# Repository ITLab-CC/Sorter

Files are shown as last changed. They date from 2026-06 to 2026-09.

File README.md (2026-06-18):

# AI-Sorter

An AI-powered marble sorting machine. A camera detects falling marbles, a neural network classifies them by color, and a solenoid actuator sorts them into the correct bin — all in real time on a Raspberry Pi with a Coral Edge TPU.

## What You Need

This project requires **two machines**:

### Raspberry Pi (runs the sorter)

| Component | Description |
|---|---|
| **Raspberry Pi** | Runs the sorting software (tested on Pi 4/5, Ubuntu 22.04 ARM64) |
| **FLIR Machine Vision Camera** | Captures images of marbles (uses the Spinnaker SDK) |
| **Coral USB Accelerator** | Runs the trained model for real-time inference (~6 ms/frame) |
| **Elevator motor** | Feeds marbles into the sorting area |
| **Solenoid actuator** | Diverts marbles into the correct bin |
| **NeoPixel LED strip** | Illuminates the sorting area for consistent images |
| **Light-beam sensor** | Detects when a marble passes through |

### Training PC (trains the AI model)

| Component | Description |
|---|---|
| **PC with NVIDIA GPU** | Trains the SSD MobileNet V2 model (fine-tuning ~50 000 steps) |
| **Docker + NVIDIA Container Toolkit** | The training pipeline runs inside a Docker container with GPU access |

> The training PC can be a local desktop, a cloud VM (AWS EC2, Google Cloud, etc.), or Google Colab. **Do not attempt training on the Raspberry Pi.**

## Step-by-Step Guide

Follow the guides below in order:

| Step | Guide | Machine |
|---|---|---|
| 0 | [Build the Sorter](docs/00-build-the-sorter.md) | Workbench |
| 1 | [Raspberry Pi Setup](docs/01-raspberry-pi-setup.md) | Raspberry Pi |
| 2 | [Training PC Setup](docs/02-training-pc-setup.md) | Training PC |
| 3 | [Create a Dataset](docs/03-create-dataset.md) | Raspberry Pi |
| 4 | [Train the Model](docs/04-train-model.md) | Training PC |
| 5 | [Run the Sorter](docs/05-run-sorter.md) | Raspberry Pi |

> **Don't want to train your own model?** A **pretrained, ready-to-use** model
> is included in [`my-models-example/`](my-models-example/README.md). Just copy
> that folder's contents into `my-models/` and skip straight to
> [Step 5 — Run the Sorter](docs/05-run-sorter.md) (you can ignore Steps 2–4).
> See [Step 5](docs/05-run-sorter.md) for the exact copy command.

## Project Structure

```
.
├── actuator/          # Motor, solenoid and LED control
├── sensor/            # Camera and light-beam sensor
├── dataset/           # Training images (created in step 3)
├── my-models/         # Trained models (created in step 4, git-ignored)
├── my-models-example/ # Pretrained ready-to-use model (copy into my-models/)
├── docs/              # Step-by-step setup guides
├── create_unlabeled_dataset.py
├── label_dataset.py
├── label_map.pbtxt    # Single source of truth for class labels
├── main.py            # Entry point for the sorter
├── Dockerfile.train   # Docker image for training
└── pipeline.config    # SSD MobileNet V2 training config
```

## Label Map (`label_map.pbtxt`)

`label_map.pbtxt` is the **single source of truth** for all class labels used throughout the project. Every script — labeling, TFRecord generation, training, and inference — reads its labels from this file. Never hardcode label names or IDs elsewhere.

The file uses the [TensorFlow Object Detection API label map format](https://github.com/tensorflow/models/blob/master/research/object_detection/data/kitti_label_map.pbtxt). Each class gets an `item` block with a unique `id` (starting at 1) and a `name`:

```protobuf
item {
  id: 1
  name: 'black'
}

item {
  id: 2
  name: 'green'
}

item {
  id: 3
  name: 'orange'
}

item {
  id: 4
  name: 'red'
}

```

To add or change marble colors:

1. Edit `label_map.pbtxt` — add, remove, or rename entries.
2. Make sure a matching `dataset/<name>/` folder with images exists for each label (see [Step 3](docs/03-create-dataset.md)).
3. Update `num_classes` in `pipeline.config` to match the number of items in `label_map.pbtxt`.
4. Re-run the labeling and training pipeline as usual — all scripts pick up the changes automatically.

## Sources

- **Model:** [SSD MobileNet V2 320x320 (COCO17 TPU-8)](http://download.tensorflow.org/models/object_detection/tf2/20200711/ssd_mobilenet_v2_320x320_coco17_tpu-8.tar.gz)
- **Framework:** [TensorFlow Object Detection API](https://github.com/tensorflow/models/tree/master/research/object_detection)
- **Edge TPU compiler:** [coral.ai/docs/edgetpu/compiler](https://coral.ai/docs/edgetpu/compiler/)

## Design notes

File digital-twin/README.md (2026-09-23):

# KI-Sorter · Digitaler Zwilling

Interaktives 3D-Modell des Murmelsortierers als Next.js-Web-App. Die App lädt
die **originalen 3MF-Dateien** aus [`../3d-files/3mf`](../3d-files/3mf), setzt sie
wie im echten Aufbau zusammen und zeigt den Ablauf:

```
Vorratskasten → Archimedes-Schnecke → Steigrohr → Trichter → Kamerakammer (LED + FLIR)
             → Erkennung → Hubmagnet kippt die Rinne → Auslauf links / rechts → Becher
```

Es gibt keine KI und keine Physik-Simulation: Die Murmeln folgen fest definierten
Wegpunkten. Das Modell zeigt, wie die Maschine funktioniert, und lässt sich später
über einen WebSocket mit dem echten Sorter verbinden.

## Starten

```bash
cd digital-twin
npm install
npm run dev          # http://localhost:3000
```

`npm run dev` / `npm run build` kopieren vorher automatisch alle `.3mf` aus
`../3d-files/3mf` nach `public/models` (`scripts/sync-models.mjs`). Wer ein Teil in
Fusion neu exportiert, sieht es also direkt in der Web-App.

Deep-Links für Präsentationen: `/?view=chamber`, `/?view=gate&xray=1`
(`overview`, `chamber`, `gate`, `transporter`).

## Bedienung

- **Simulation**: START/STOP wie am Touchscreen, Murmeln einer Farbe gezielt einwerfen,
  Zähler zurücksetzen.
- **Echter Sorter**: WebSocket-Adresse eintragen und verbinden, dann zeigt das Modell
  den Live-Zustand des Raspberry Pi.
- Maus über ein Bauteil zeigt Name, Funktion und Quelldatei. Klick hält die Auswahl fest.
- **Röntgenblick** macht die Gehäuse durchsichtig, so sieht man die Murmel in Kammer,
  Weiche und Steigrohr.
- Baugruppen lassen sich einzeln ausblenden.

Sortierregel wie in `main.py`: Grün/Orange → Magnet AN → **links**,
Rot/Schwarz → Magnet AUS → **rechts**.

## Anbindung an den echten Sorter

Die App ist so gebaut, dass nur die Datenquelle wechselt, die Szene bleibt gleich:

| Datei | Aufgabe |
|---|---|
| `lib/twin/types.ts` | Datenmodell (`TwinState`) und Nachrichtenformat (`LiveMessage`) |
| `lib/twin/store.ts` | Zustand + Ereignisse (`release`, `detection`) |
| `lib/twin/sources.ts` | `SimulationSource` (Demo) und `LiveSource` (WebSocket) |
| `bridge/twin_bridge.py` | WebSocket-Server für den Raspberry Pi |

Nachrichten (JSON, eine pro WebSocket-Frame; alle `state`-Felder optional):

```json
{"type": "state", "running": true, "motor": true, "solenoid": false,
 "led": {"rgb": [255, 255, 255], "brightness": 0.5}}
{"type": "detection", "label": "green", "confidence": 0.93, "side": "left"}
{"type": "release", "label": "red"}
{"type": "reset"}
```

Ohne Hardware testen:

```bash
pip install websockets
python bridge/twin_bridge.py --demo
# Web-App → „Echter Sorter“ → ws://localhost:8765 → Verbinden
```

Später in `main.py` einbinden (nicht blockierend, eigener Thread):

```python
from twin_bridge import TwinBridge          # Datei auf den Pi kopieren
twin = TwinBridge(port=8765); twin.start()

# bei START / STOP
twin.state(running=True, motor=True, led=((255, 255, 255), 0.5))
twin.state(running=False, motor=False, solenoid=False, led=((0, 255, 0), 0.05))

# nach jeder Klassifizierung
twin.detection(label, confidence / 100, "left" if label in ("green", "orange") else "right")
twin.state(solenoid=label in ("green", "orange"))
```

## Aufbau des 3D-Modells

- Alle Teile werden in einem gemeinsamen Koordinatensystem platziert:
  Z oben, Millimeter, Tischplatte bei z = 0 (`lib/layout.ts`).
- Jedes Teil hat `basis` (Ausrichtung), `pivot` (Bezugspunkt im Teil) und `at`
  (Position in der Welt). Die Maße stammen direkt aus den Meshes.
- Zukaufteile ohne 3MF-Datei (NEMA-17, FLIR-Kamera mit Objektiv, 7"-Display,
  NeoPixel-Ring, Platinen, Laborstativ) sind einfache Grundkörper
  (`components/scene/Hardware.tsx`).
- `/debug?part=Kamera/main_chamber,Kamera/Deckel` zeigt Teile in ihrem eigenen
  Koordinatensystem aus vier Richtungen. Das hilft beim Ausrichten neuer Teile.

Bewusst weggelassen: `Case.3mf` (auf den Fotos nicht verbaut),
`Kurbelschleifen_Funktionstester.3mf` (Testvorrichtung), `Kurbelschleife.3mf`
(sitzt verdeckt im Magnetgehäuse der Weiche). Die Anordnung ist nach den
Aufbaufotos rekonstruiert. Hilfsstützen aus der Bauphase fehlen.

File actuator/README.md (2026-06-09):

# Information about the Actuator module.
This folder contains the code for the Actuator module, which is responsible for controlling the physical components of the system. It includes code for:
- Motor elevator for marbles
- Solenoid motor for a marble switch to change the path of the marbles
- LED neopixel ring to make a picture of the marbles falling down

# Installation

```bash
python3 -m venv .venv-3.10
source .venv-3.10/bin/activate
pip install -r requirements-3.10.txt
```

# Usage

```bash
sudo .venv-3.10/bin/python [script].py
```

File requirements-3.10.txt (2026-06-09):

numpy<2
Pillow
opencv-python
# Wheels from https://github.com/cappittall/pycoral_whl_4_python3.10/tree/main/tools
# Install manually:
#   pip install ./tflite_runtime-2.5.0.post1-cp310-cp310-linux_x86_64.whl
#   pip install ./pycoral-2.0.0-cp310-cp310-linux_x86_64.whl

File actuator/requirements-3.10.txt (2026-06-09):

mypy
RPi.GPIO
Adafruit-Blinka
adafruit-circuitpython-neopixel
gpiozero

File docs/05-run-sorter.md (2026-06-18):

# Step 5 — Run the Sorter

You now have a trained Edge TPU model. Time to sort some marbles.

> **Machine:** Raspberry Pi

## 5.1 Get a model into `my-models/`

The sorter loads its model from the `my-models/` folder (which is git-ignored). You have two options:

### Option A — Use the included pretrained model (no training required)

If you don't want to train your own model, a **pretrained, ready-to-use** model ships with the project in `my-models-example/`. Just copy its contents into `my-models/`:

```bash
# From the project root, on the Raspberry Pi
mkdir -p my-models
cp my-models-example/marbel_coral.tflite my-models-example/labels.txt my-models/
```

That's it — you can skip Steps 2–4 entirely. See [`my-models-example/README.md`](../my-models-example/README.md) for details about the model.

### Option B — Use your own trained model

If you completed [Step 4 — Train the Model](04-train-model.md), transfer `my-models/marbel_coral.tflite` and `my-models/labels.txt` from the training PC to the Raspberry Pi project directory (inside `my-models/`).

## 5.2 Start the sorter

Make sure the camera, Coral USB Accelerator, motors, and sensors are all connected, then run:

```bash
sudo .venv-3.10/bin/python main.py
```

Enjoy your sorted marbles!

## 5.3 Run automatically on boot (autostart)

To make the sorter start by itself once the desktop appears, use the **labwc** autostart script (Raspberry Pi OS Bookworm/trixie use the labwc Wayland compositor).

We run the app inside a detached [`screen`](https://www.gnu.org/software/screen/) session named `sorter`, so you can attach later to see its console output.

1. Make sure `screen` is installed:

   ```bash
   sudo apt install screen
   ```

2. Create the file `~/.config/labwc/autostart` with the following contents (adjust the paths if your project lives elsewhere):

   ```sh
   #!/bin/sh
   # Start the marble sorter app in a detached screen session after the desktop comes up
   cd /home/sorter/Documents/Sorter
   screen -dmS sorter sudo --preserve-env=WAYLAND_DISPLAY,XDG_RUNTIME_DIR .venv-3.10/bin/python main.py
   ```

   - `screen -dmS sorter` starts a **d**etached, na**m**ed (`sorter`) session in the background.
   - `sudo --preserve-env=WAYLAND_DISPLAY,XDG_RUNTIME_DIR` lets the root process reach the Wayland display (required because the app runs with `sudo` under Wayland). For this to work without a password prompt, passwordless `sudo` must be configured (it is by default on Raspberry Pi OS for the default user).

3. Make it executable:

   ```bash
   chmod +x ~/.config/labwc/autostart
   ```

4. Test it without rebooting, then reboot to confirm:

   ```bash
   ~/.config/labwc/autostart
   screen -ls          # should list the "sorter" session
   sudo reboot
   ```

### Managing the running session

| Action | Command |
| --- | --- |
| Attach to / view the app console | `screen -r sorter` |
| Detach again (leave it running) | press `Ctrl+a` then `d` |
| List sessions | `screen -ls` |
| Stop the sorter | `screen -XS sorter quit` |

---

**Previous:** [Step 4 — Train the Model](04-train-model.md)
**Back to:** [README](../README.md)

[**Home**](../README.md)

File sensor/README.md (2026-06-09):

# Information about the Actuator module.
This folder contains the code for the Sensors. The sensors are responsible for collecting data from the sorter. It includes code for:
- FLIR camera (500FPS)
- Light beam sensor

# Installation

## Docker
Downloade the python and the sdk version of the Spinnaker SDK from the following link: 

https://www.teledynevisionsolutions.com/support/support-center/software-firmware-downloads/iis/spinnaker-sdk-download/spinnaker-sdk--download-files/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

There should be two files:
- For x64 (PCs):
- - (Linux Ubuntu 22.04 -- 64-bit) 'spinnaker-4.3.0.189-Ubuntu22.04-amd64-pkg.tar.gz'
- - (Linux Ubuntu 22.04 -- 64-bit Python 3.10) 'spinnaker_python-4.3.0.189-cp310-cp310-linux_x86_64.tar.gz'

```bash
sudo docker build -t sorter-actuator .
sudo docker run -it --rm \
    --privileged \
    -v /dev/bus/usb:/dev/bus/usb \
    -v $(pwd)/out:/app/out \
    --shm-size=2g \
    sorter-actuator
```

## DEV
```bash
sudo apt update 
sudo apt install -y \
    udev \
    ethtool \
    libusb-1.0-0 \
    iproute2 \
    iputils-ping \
    net-tools \
    build-essential \
    libssl-dev \
    zlib1g-dev \
    libbz2-dev \
    libreadline-dev \
    libsqlite3-dev \
    curl \
    git \
    libncursesw5-dev \
    xz-utils \
    tk-dev \
    libxml2-dev \
    libxmlsec1-dev \
    libffi-dev \
    liblzma-dev \
    libgl1 \
    libglib2.0-0 \
    ffmpeg

curl https://pyenv.run | bash

echo 'export PYENV_ROOT="$HOME/.pyenv"' >> ~/.bashrc
echo 'command -v pyenv >/dev/null || export PATH="$PYENV_ROOT/bin:$PATH"' >> ~/.bashrc
echo 'eval "$(pyenv init -)"' >> ~/.bashrc
export PYENV_ROOT="$HOME/.pyenv"
command -v pyenv >/dev/null || export PATH="$PYENV_ROOT/bin:$PATH"
eval "$(pyenv init -)"

pyenv install 3.10.20

pyenv local 3.10.20
```

```bash
python3.10 -m venv .venv-3.10
source .venv-3.10/bin/activate
export SPINNAKER_GENTL64_CTI=/opt/spinnaker/lib/spinnaker-gentl/Spinnaker_GenTL.cti
pip install -r requirements-3.10.txt
```
---

Downloade the python and the sdk version of the Spinnaker SDK from the following link: 

https://www.teledynevisionsolutions.com/support/support-center/software-firmware-downloads/iis/spinnaker-sdk-download/spinnaker-sdk--download-files/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

There should be two files:
- For ARM (Raspberry PIs):
- - (Linux Ubuntu 22.04 --ARM64) 'spinnaker-4.3.0.189-Ubuntu22.04-arm64-pkg.tar.gz'
- - (Linux Ubuntu 22.04 -- ARM64 Python 3.10) 'spinnaker_python-4.3.0.189-cp310-cp310-linux_aarch64.tar.gz'

```bash
mkdir -p spinnaker_sdk spinnaker_python
tar -xzvf spinnaker-4.3.0.189-Ubuntu22.04-arm64-pkg.tar.gz -C spinnaker_sdk
tar -xzvf spinnaker_python-4.3.0.189-cp310-cp310-linux_aarch64.tar.gz -C spinnaker_python

cd spinnaker_sdk/spinnaker-4.3.0.189-arm64/
./install_spinnaker_arm.sh

cd ../../spinnaker_python
pip3 install spinnaker_python-4.3.0.189-cp310-cp310-linux_aarch64.whl

cd ..
rm -rf spinnaker_python spinnaker_sdk
```

---

- For x64 (PCs):
- - (Linux Ubuntu 22.04 -- 64-bit) 'spinnaker-4.3.0.189-Ubuntu22.04-amd64-pkg.tar.gz'
- - (Linux Ubuntu 22.04 -- 64-bit Python 3.10) 'spinnaker_python-4.3.0.189-cp310-cp310-linux_x86_64.tar.gz'

```bash
mkdir -p spinnaker_sdk spinnaker_python
tar -xzvf spinnaker-4.3.0.189-Ubuntu22.04-amd64-pkg.tar.gz -C spinnaker_sdk
tar -xzvf spinnaker_python-4.3.0.189-cp310-cp310-linux_x86_64.tar.gz -C spinnaker_python

cd spinnaker_sdk/spinnaker-4.3.0.189-amd64/
./install_spinnaker.sh

cd ../../spinnaker_python
pip3 install spinnaker_python-4.3.0.189-cp310-cp310-linux_x86_64.whl

cd ..
rm -rf spinnaker_python spinnaker_sdk
```

# Usage

```bash
sudo .venv-3.10/bin/python [script].py
```

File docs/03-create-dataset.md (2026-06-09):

# Step 3 — Create a Dataset

This guide walks you through capturing marble images and labeling them for training.

> **Machine:** Raspberry Pi

## 3.1 Capture images

Put only **one color** of marbles in the sorter at a time. Aim for at least **200 images per color**.

```bash
sudo .venv-3.10/bin/python create_unlabeled_dataset.py
```

The script will ask you for:
1. **Label name** — the marble color (e.g. `red`). The label is automatically added to `label_map.pbtxt` (skipped if it already exists) and the matching `dataset/<name>/` folder is created.
2. **Capture time** — how many seconds to run the camera.

To lift the elevator motor so you can swap marbles more easily:

```bash
sudo .venv-3.10/bin/python actuator/elevator_motor.py
```

Repeat for every color. You should end up with a folder structure like this:

```
dataset/
├── black/
│   ├── frame_0000.png
│   ├── frame_0001.png
│   └── ...
├── orange/
│   ├── frame_0000.png
│   └── ...
├── green/
│   └── ...
├── red/
│   └── ...
└── ...
```

## 3.2 Auto-label the images

This script uses OpenCV to detect marbles and generate bounding-box labels automatically. It reads the class names from `label_map.pbtxt` and processes only `dataset/` subfolders that match those names. The results are saved as `dataset-<color>.json` files inside the `dataset/` folder.

```bash
sudo .venv-3.10/bin/python label_dataset.py
```

Result should look like this:
```
dataset/
├── black
├── green
├── mixed-not-labeled
├── orange
├── red
├── white
├── dataset-black.json
├── dataset-green.json
├── dataset-orange.json
├── dataset-red.json
└── dataset-white.json
```

> The auto-labeler is not perfect — you **must** review and correct the labels in the next step.

## 3.3 Review labels with Label Studio

### Start Label Studio

```bash
curl -sSL https://get.docker.com | sudo sh
```

```bash
mkdir -p label-studio
sudo chown :0 label-studio
sudo docker run --network host \
  -v $(pwd)/label-studio:/label-studio/data \
  --name label-studio -d heartexlabs/label-studio:latest

echo "Label Studio is starting up. Please wait a moment (1min)..."
sleep 60
echo "Label Studio should now be running at http://localhost:8080 (oder über die IP-Adresse des Hosts)"
```

Open <http://localhost:8080> in your browser.

### Serve images locally

Label Studio needs HTTP access to the images. Start the included server on port 1000:

```bash
sudo python3 http-server.py
```

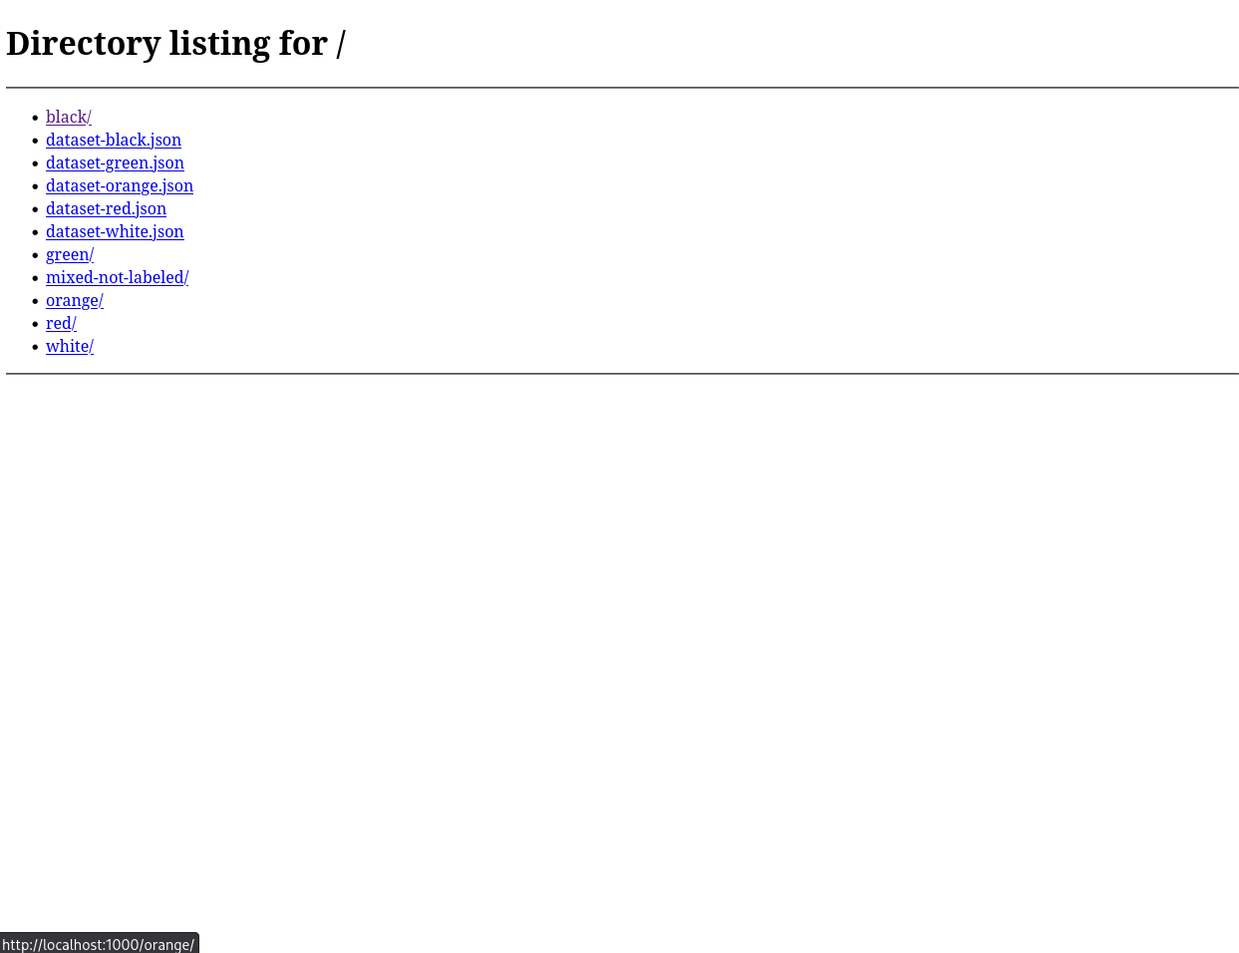
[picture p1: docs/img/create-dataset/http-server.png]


### Import and review

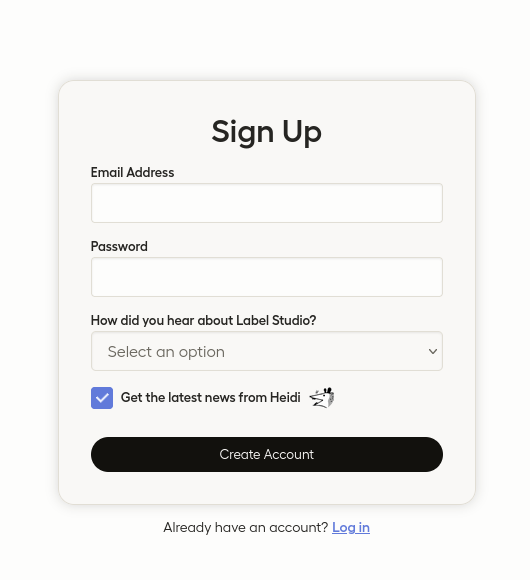
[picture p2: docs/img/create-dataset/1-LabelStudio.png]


1. Click **Import** in Label Studio.
2. Upload the `dataset-<color>.json` files from the `dataset/` folder.
3. Review each image and correct any wrong bounding boxes.

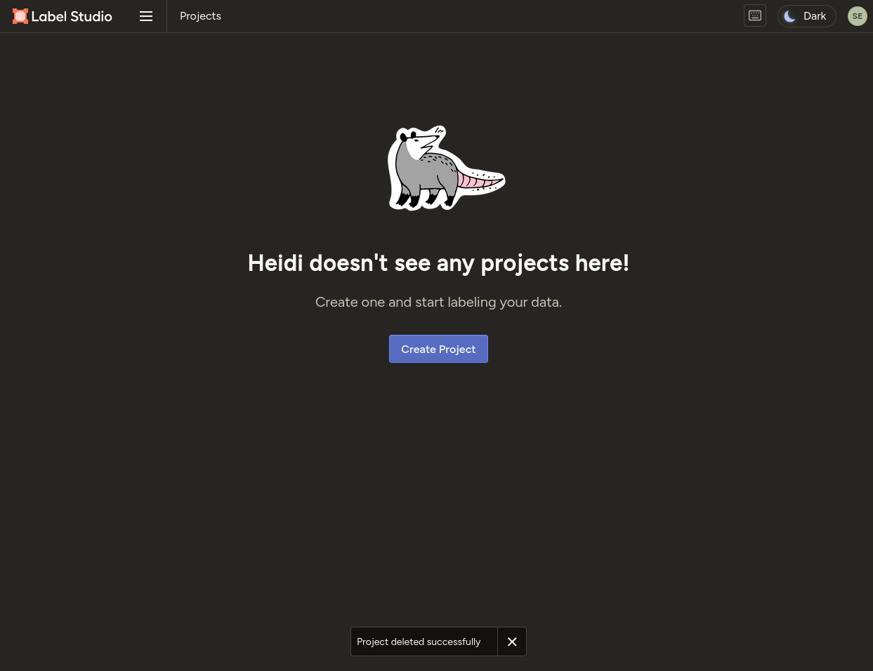
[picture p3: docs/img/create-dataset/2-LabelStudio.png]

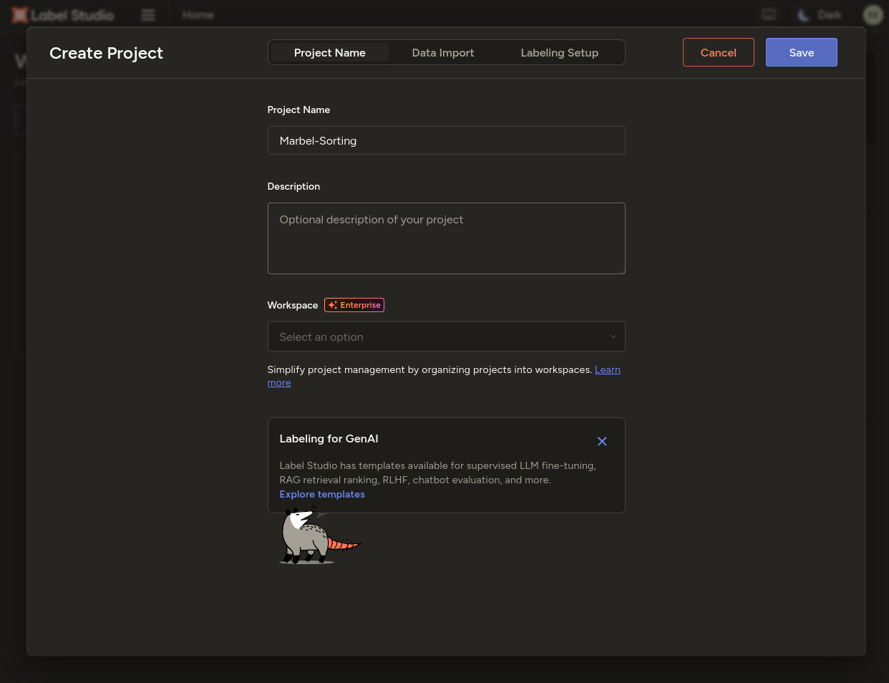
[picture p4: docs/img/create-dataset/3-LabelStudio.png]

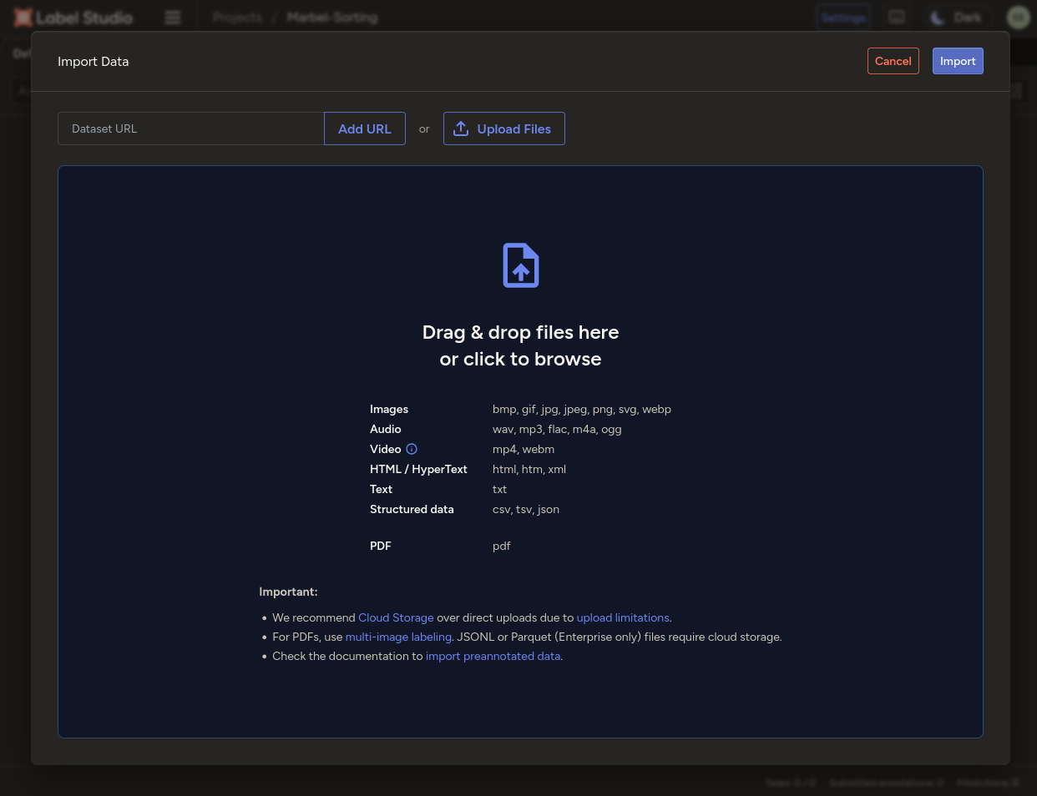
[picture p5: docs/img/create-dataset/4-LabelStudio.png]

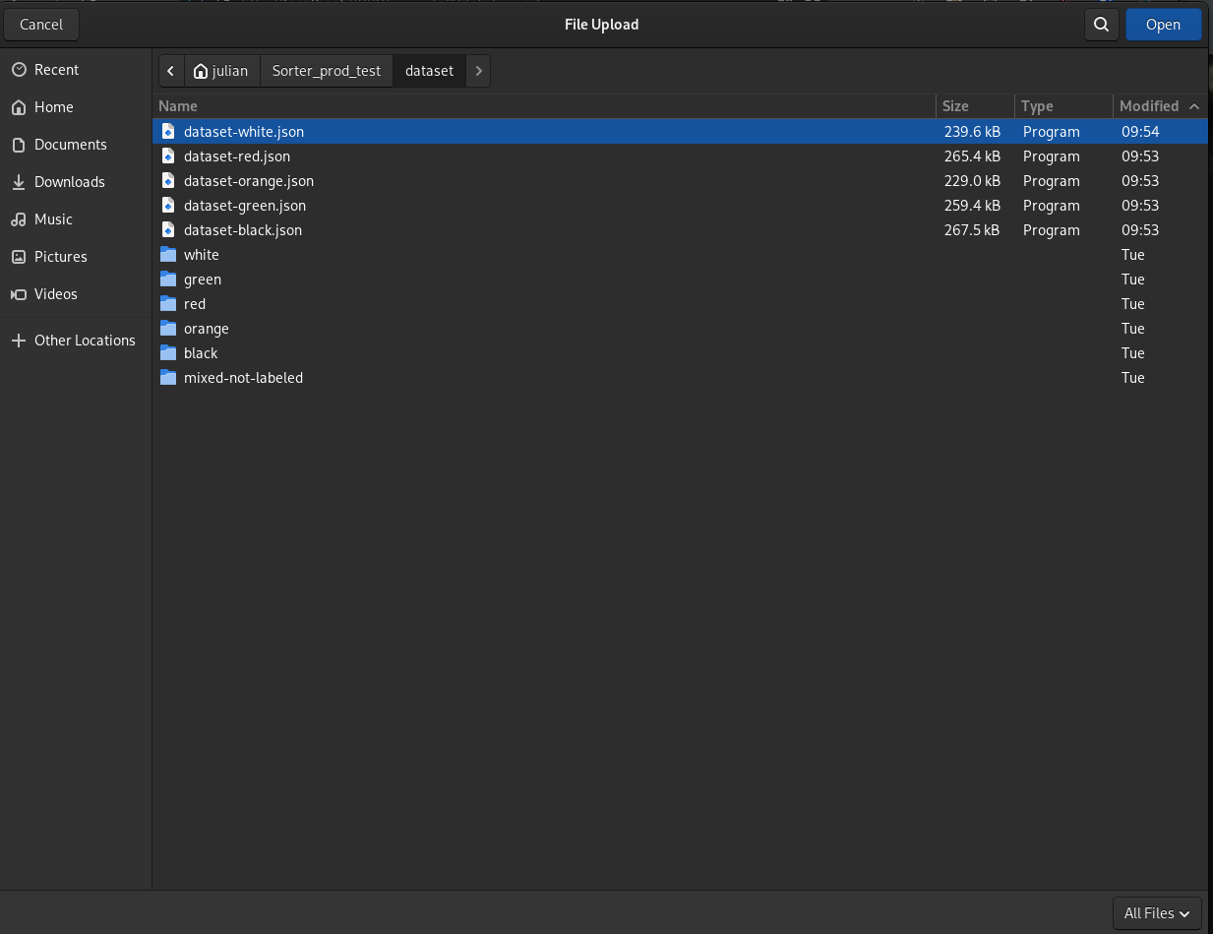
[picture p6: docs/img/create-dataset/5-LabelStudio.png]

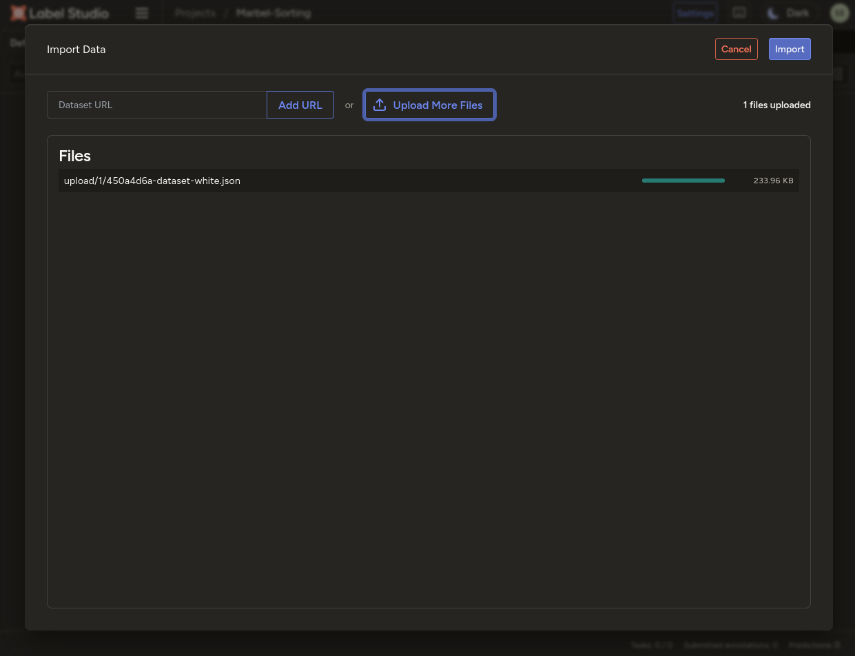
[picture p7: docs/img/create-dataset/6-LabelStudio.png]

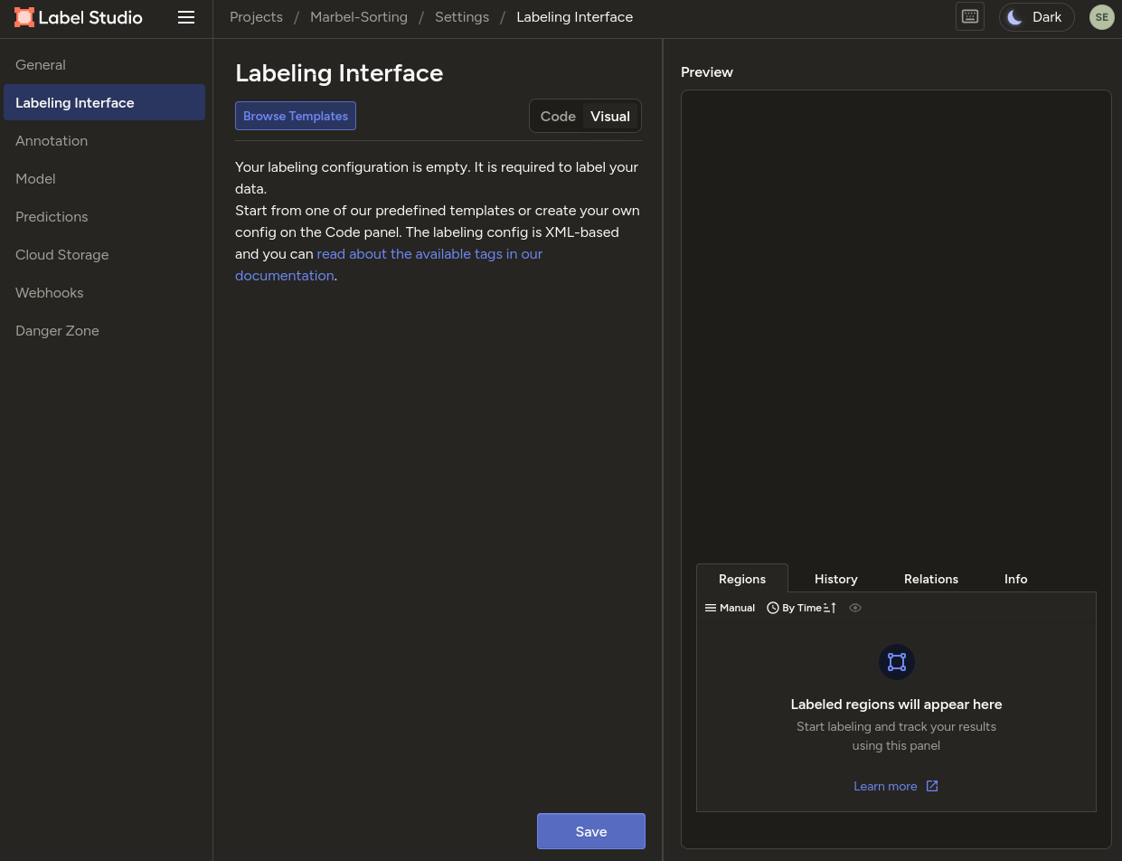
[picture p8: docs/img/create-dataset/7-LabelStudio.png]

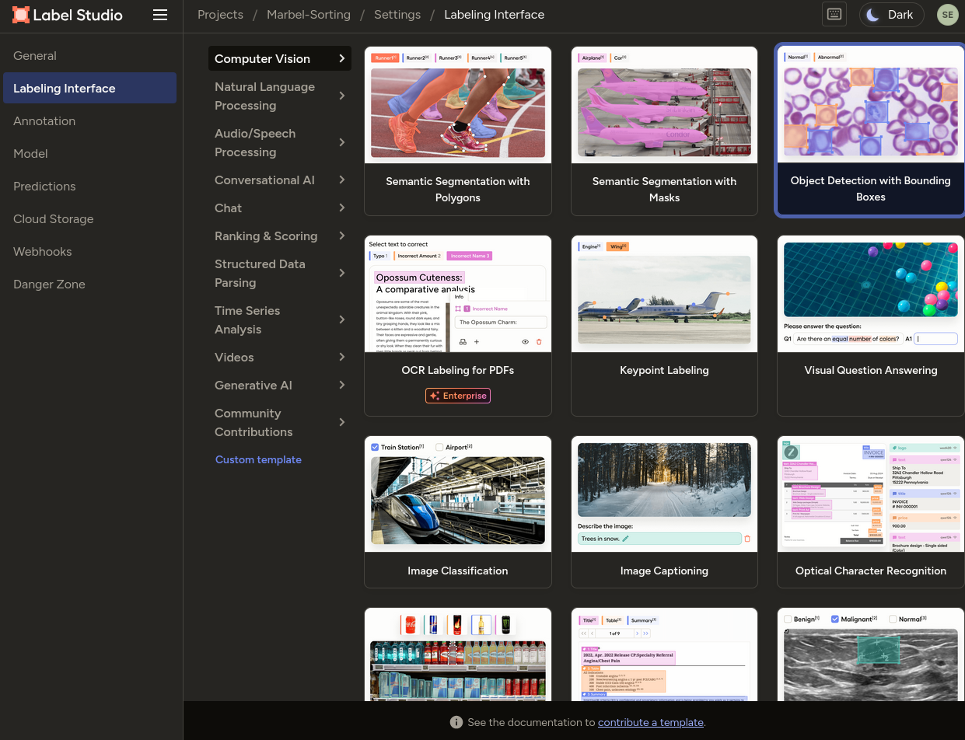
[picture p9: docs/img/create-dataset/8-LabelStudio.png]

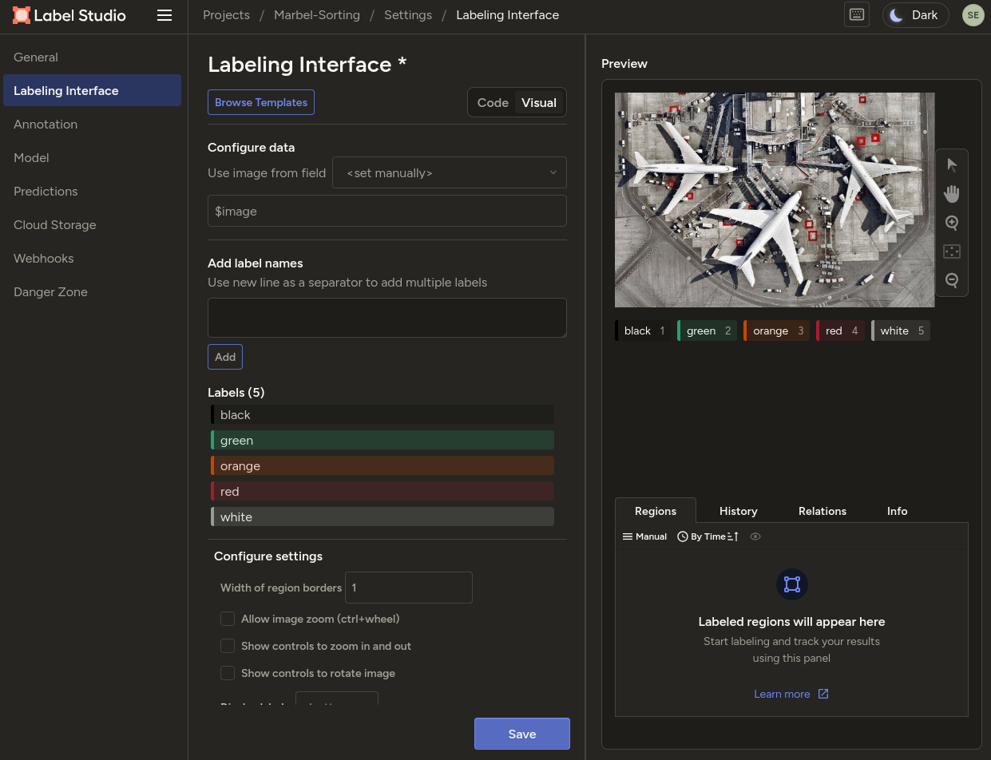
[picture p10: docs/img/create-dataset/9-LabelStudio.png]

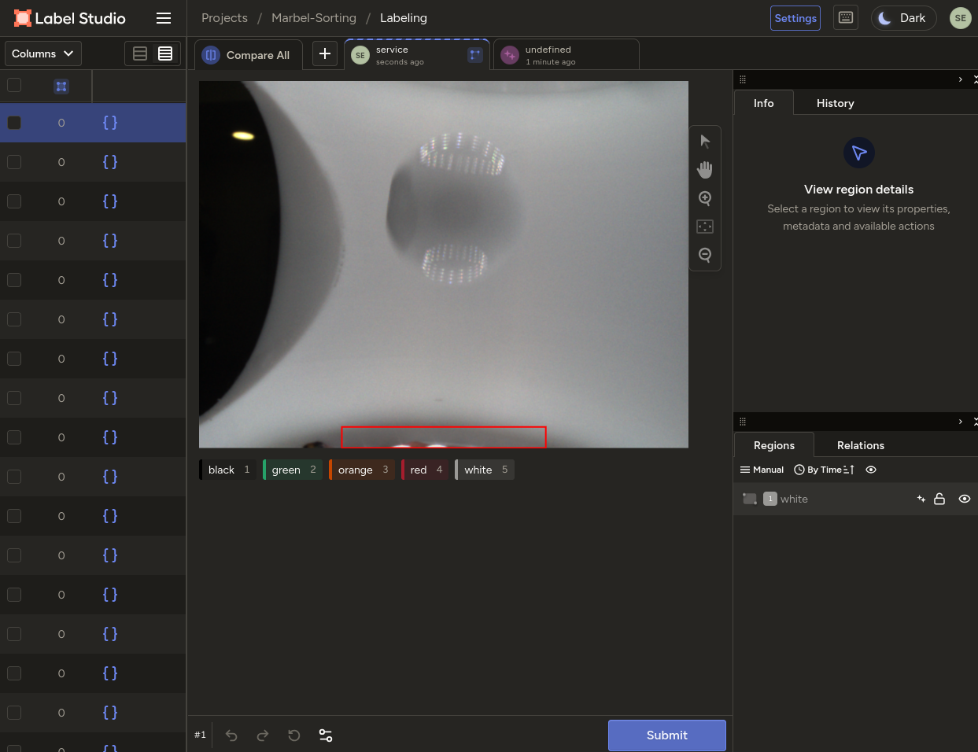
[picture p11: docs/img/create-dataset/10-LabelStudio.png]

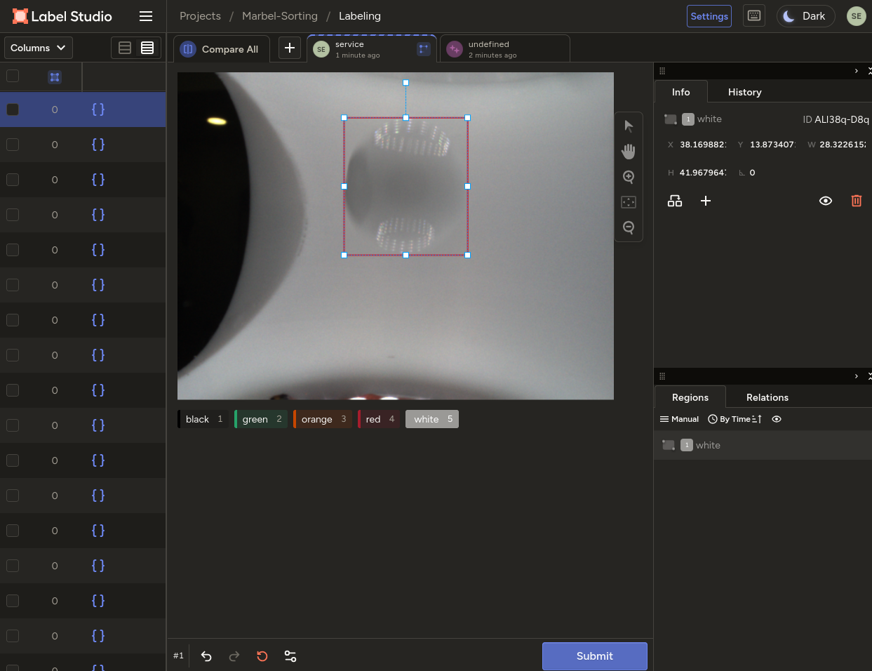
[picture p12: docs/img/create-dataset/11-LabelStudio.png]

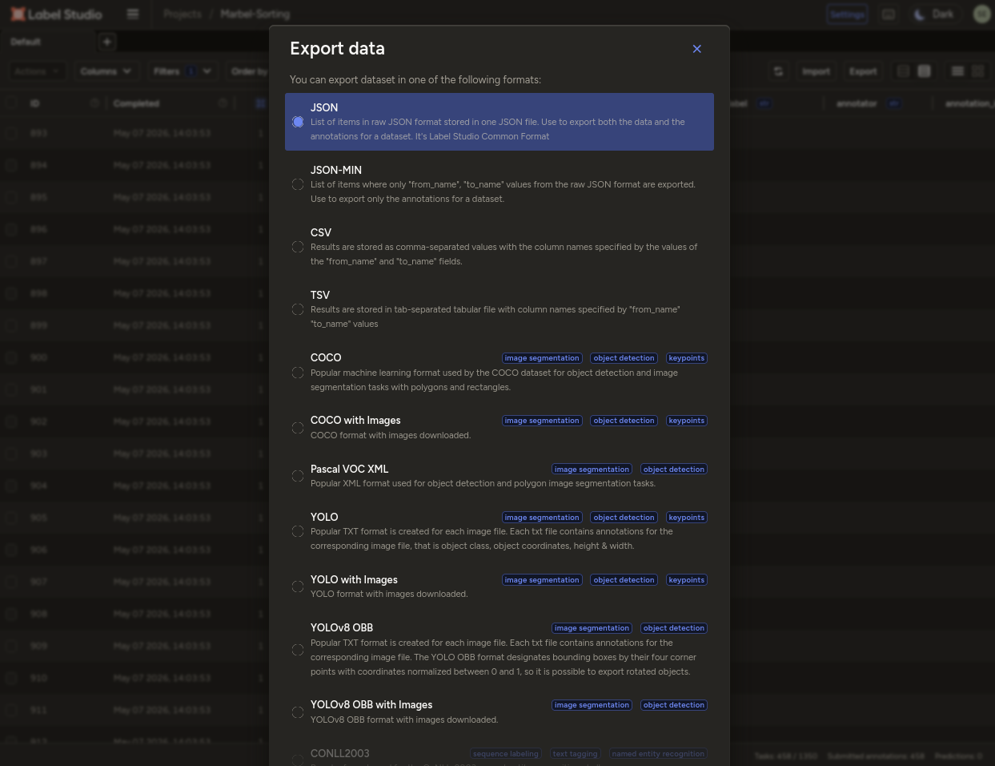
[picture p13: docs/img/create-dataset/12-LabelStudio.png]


Once you are happy with the labels, you are ready to train the model.

---

**Previous:** [Step 2 — Training PC Setup](02-training-pc-setup.md)
**Next:** [Step 4 — Train the Model](04-train-model.md)

[**Home**](../README.md)

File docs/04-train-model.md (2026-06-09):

# Step 4 — Train the Model

A single Docker container performs the complete training pipeline — TFRecord generation, SSD MobileNet V2 fine-tuning, TFLite export, INT8 quantization, and Edge TPU compilation.

> **Machine:** Training PC with NVIDIA GPU
> Make sure you have completed [Step 2 — Training PC Setup](02-training-pc-setup.md) first.

## 4.1 Copy the dataset to the training PC

Transfer the `dataset/` folder (with both the per-color image folders **and** the `dataset-*.json` files from Label Studio) to the project root on your training PC.

## 4.2 Run the full training pipeline

```bash
sudo docker build -f Dockerfile.train -t sorter-train:latest .
```

```bash
mkdir -p my-models

sudo docker run --rm \
  -v "$(pwd)/dataset:/dataset" \
  -v "$(pwd)/my-models:/my-models" \
  --gpus all \
  sorter-train:latest
```

The container will, in order:

1. Generate `train.record` / `val.record` (90/10 split) into `my-models/records/`.
2. Render a container-friendly `pipeline.config` into `my-models/pipeline.config`.
3. Fine-tune SSD MobileNet V2 (`num_steps: 50000`) — checkpoints land in `my-models/checkpoints/`.
4. Export a TFLite-friendly `saved_model/` into `my-models/tflite_export/`.
5. Quantize to INT8 using ~100 calibration images from the dataset, producing `my-models/ssd_mobilenet_v2_quant.tflite`.
6. Compile for the Edge TPU, producing `my-models/ssd_mobilenet_v2_quant_edgetpu.tflite`.

## 4.3 Output files

When training finishes you will find in `my-models/`:

| File | Description |
|---|---|
| `marbel_coral.tflite` | Edge TPU model — use this on the Raspberry Pi |
| `ssd_mobilenet_v2_quant.tflite` | INT8 CPU fallback |
| `tflite_export/saved_model/` | Pre-quantization SavedModel |
| `checkpoints/` | Training checkpoints + TensorBoard event files |
| `labels.txt` | Class id-to-name map matching `label_map.pbtxt` |

## 4.4 Quick smoke test

To sanity-check the pipeline without waiting for 50 000 steps, edit `num_steps` in `pipeline.config` (e.g. to `1000`) and rebuild the image.

```bash
sudo docker build -f Dockerfile.train -t sorter-train:latest .
```

## 4.5 Test on the Coral USB Accelerator

With the coral plugged in you can also test the compiled model on the training PC, not only on the Raspberry Pi. This is a good way to verify that the model works before deploying it.

```bash
sudo .venv-3.10/bin/python test_coral.py \
  --model my-models/marbel_coral.tflite \
  --labels my-models/labels.txt \
  --image dataset/red/frame_0000.png
```

To classify all images in `dataset/mixed-not-labeled/` at once:

```bash
sudo .venv-3.10/bin/python classify_mixed.py
```

Typical inference time on the Edge TPU is ~6 ms per frame.

---

**Previous:** [Step 3 — Create a Dataset](03-create-dataset.md)
**Next:** [Step 5 — Run the Sorter](05-run-sorter.md)

[**Home**](../README.md)

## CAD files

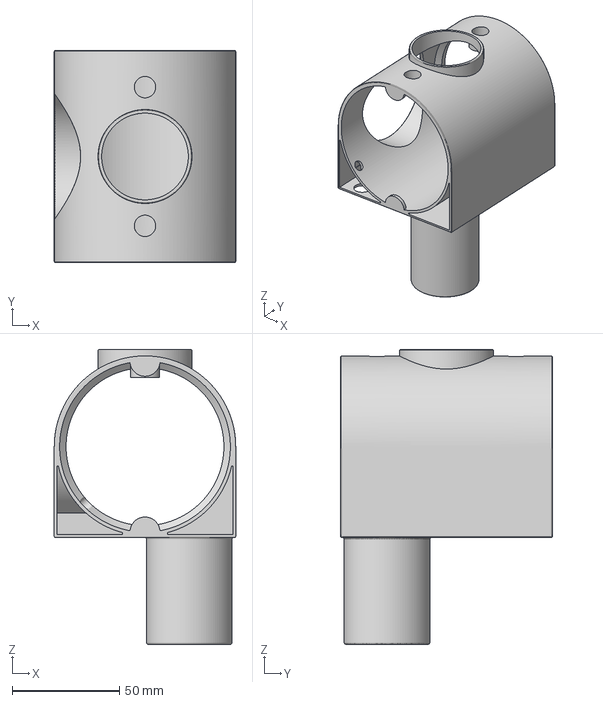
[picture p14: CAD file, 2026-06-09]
3d-files/3mf/Kamera/main_chamber.3mf
84.8 x 99.0 x 137.8 mm

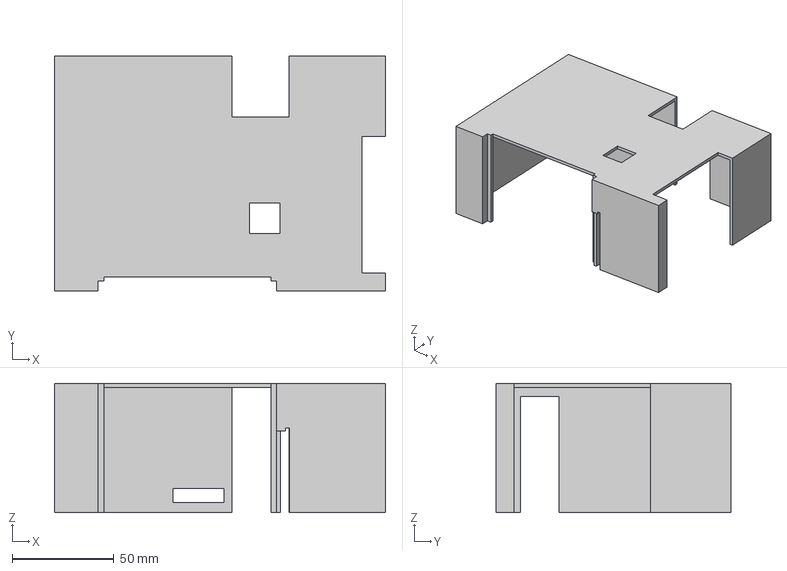
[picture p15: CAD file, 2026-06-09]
3d-files/3mf/Case.3mf
162.4 x 115.4 x 63.5 mm

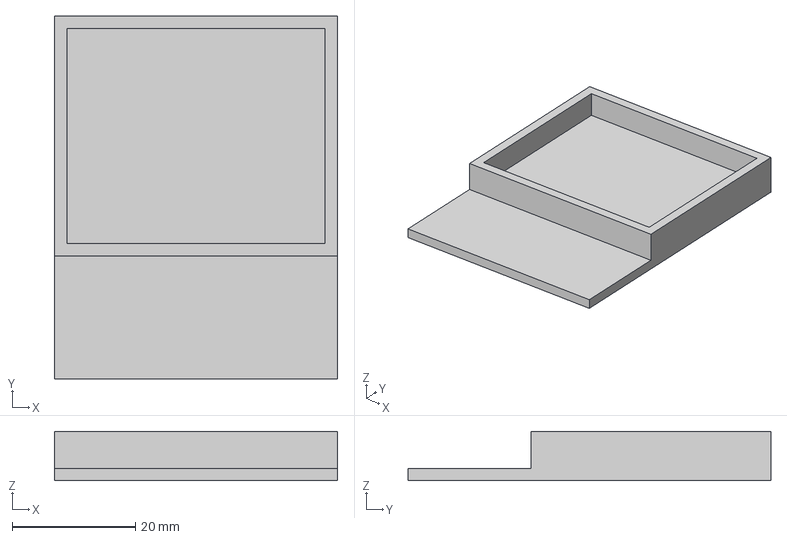
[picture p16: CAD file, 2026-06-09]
3d-files/3mf/Display/MotorController_Halterung.3mf
46.0 x 59.0 x 8.00 mm

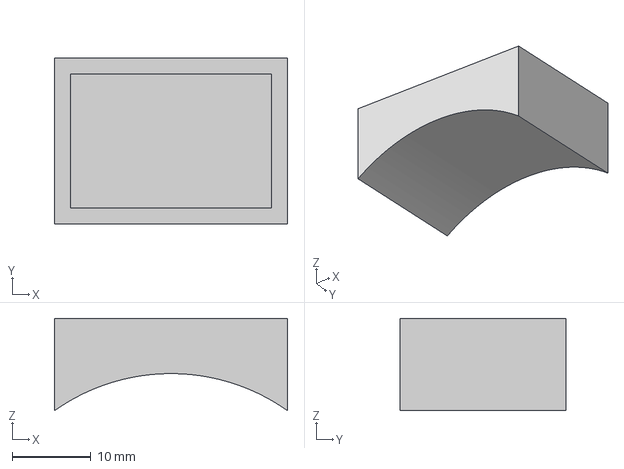
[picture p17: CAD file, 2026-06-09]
3d-files/3mf/Kamera/MCP3008_Halter.3mf
29.5 x 21.0 x 11.7 mm

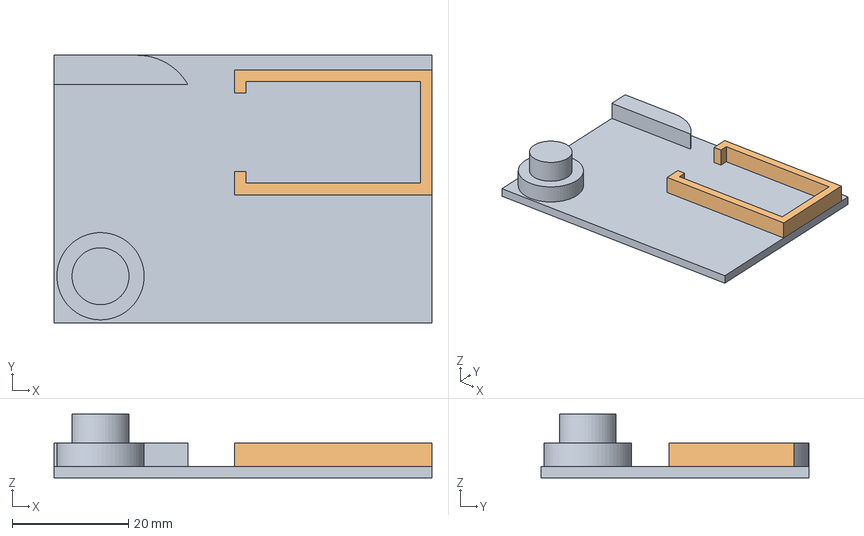
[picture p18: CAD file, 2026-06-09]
3d-files/3mf/Tippything/Kurbelschleifen_Funktionstester.3mf
65.0 x 46.0 x 11.0 mm
Körper1
Körper2

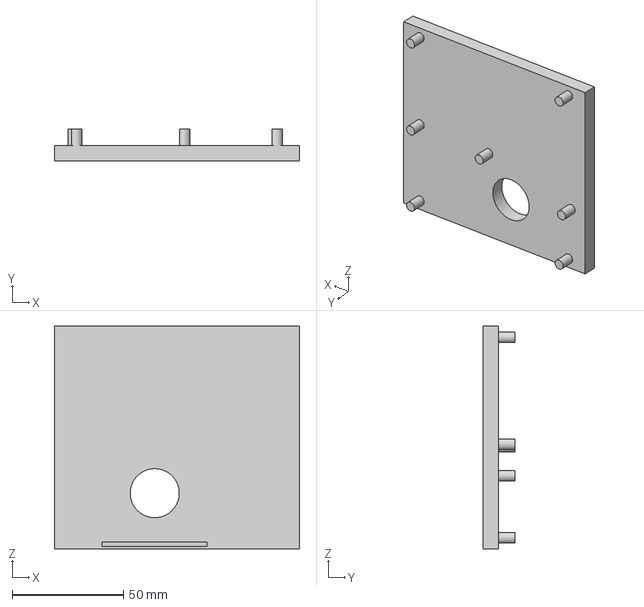
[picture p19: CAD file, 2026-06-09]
3d-files/3mf/Transporter/Transporter_Case_Wall.3mf
110.0 x 14.5 x 100.0 mm

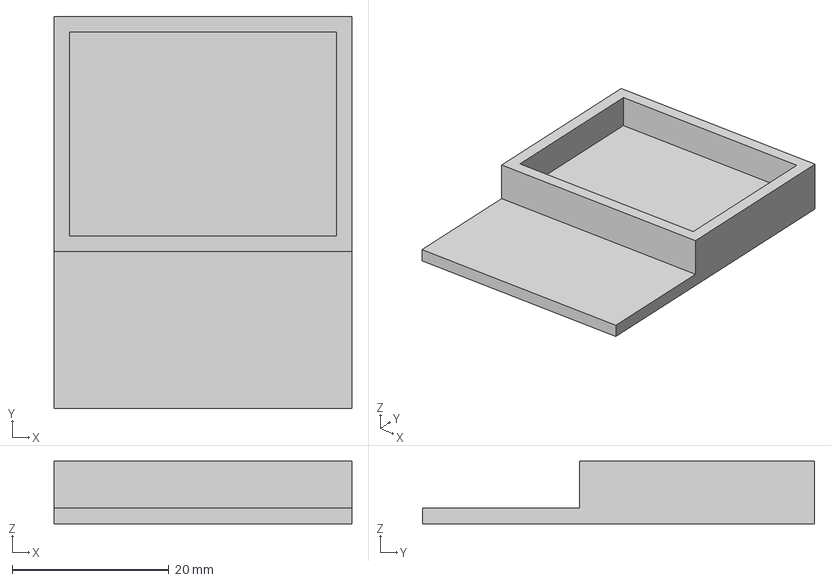
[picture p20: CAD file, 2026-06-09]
3d-files/3mf/Display/MOSFET_Halterung.3mf
38.0 x 50.0 x 8.00 mm

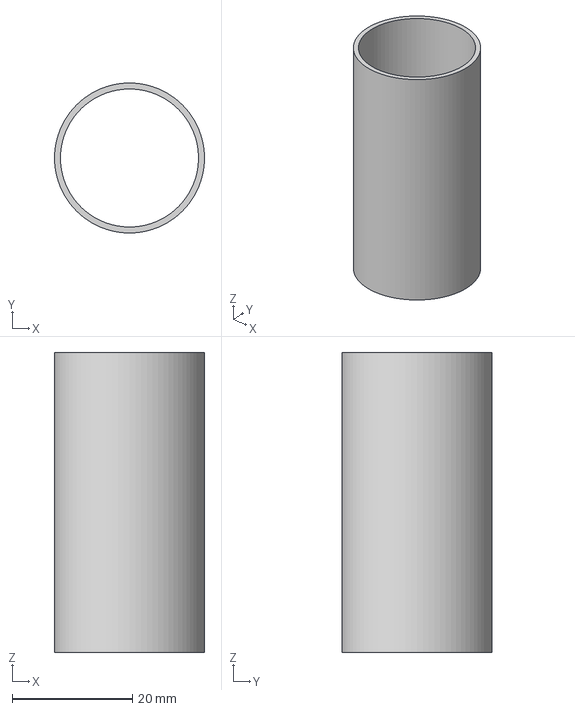
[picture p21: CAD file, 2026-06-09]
3d-files/3mf/Tippything/Rohr.3mf
25.0 x 25.0 x 50.0 mm

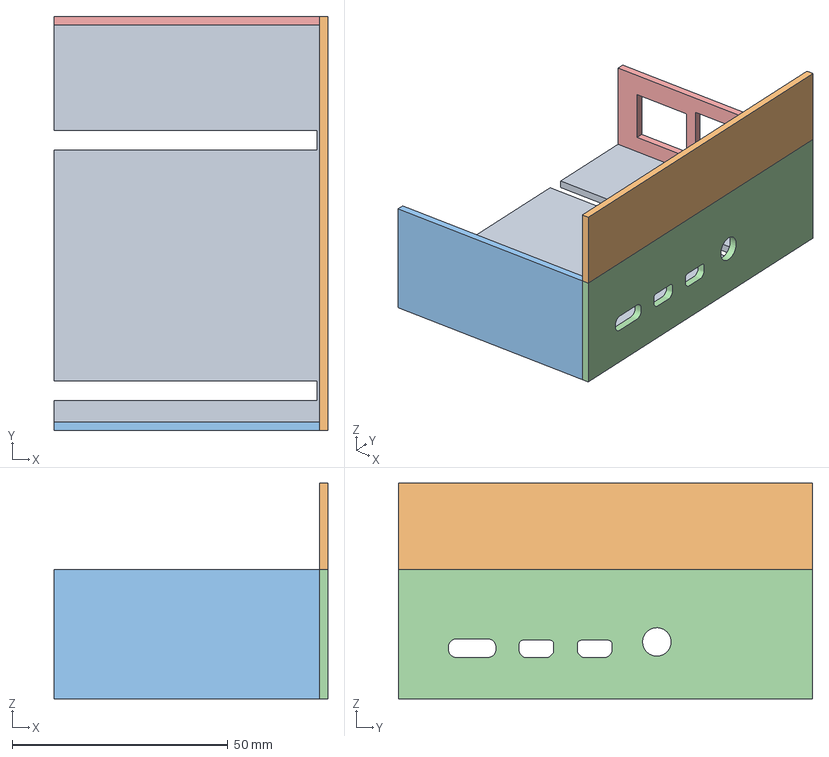
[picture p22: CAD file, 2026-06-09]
3d-files/3mf/Display/RaspberryPI_Halterung.3mf
63.5 x 96.0 x 50.0 mm
Unterteil
Wand_Clipper
Wand_Hinten
Wand_Rechts
Wand_Vorne

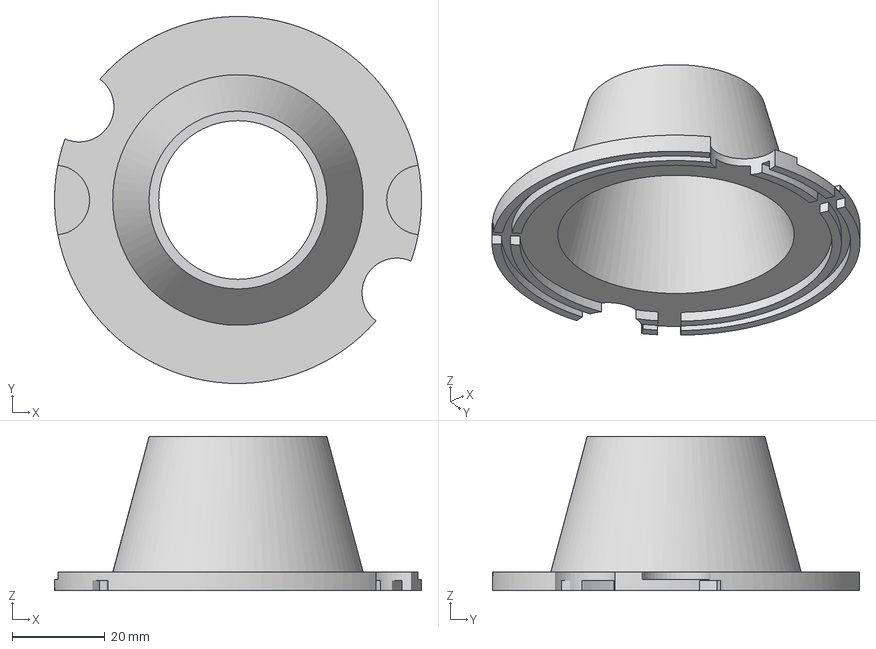
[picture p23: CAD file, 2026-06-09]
3d-files/3mf/Kamera/Unterteil.3mf
79.0 x 79.0 x 33.2 mm

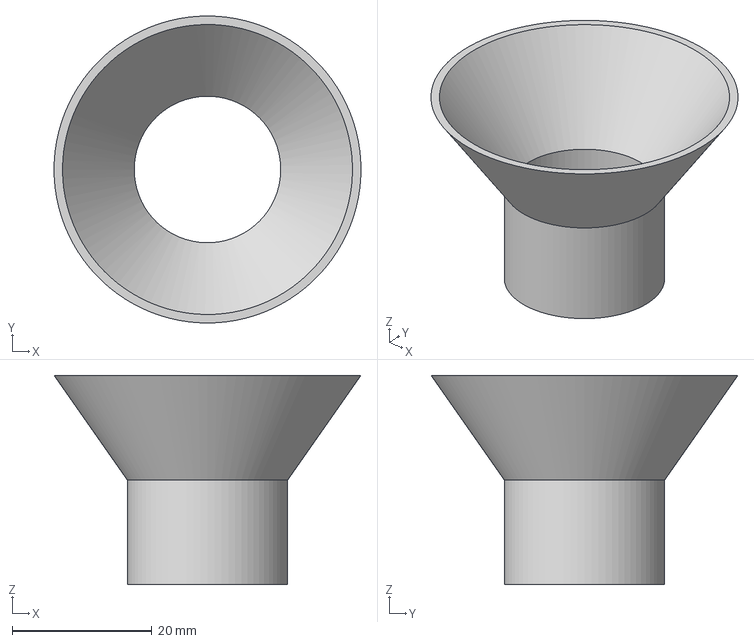
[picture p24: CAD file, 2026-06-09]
3d-files/3mf/Tippything/Trichter.3mf
44.0 x 44.0 x 30.0 mm

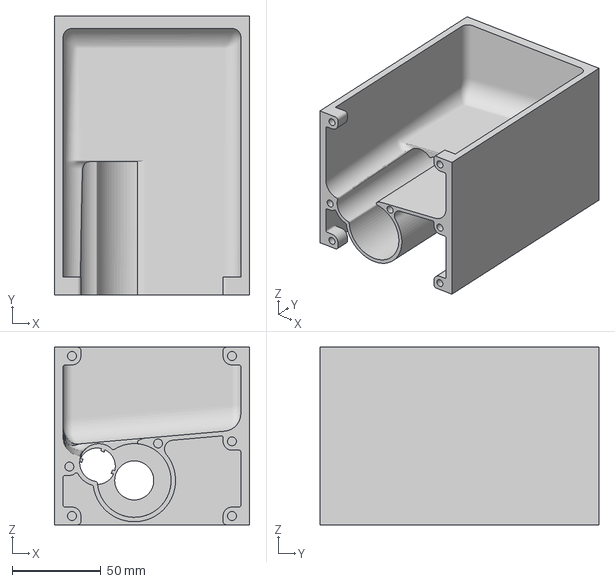
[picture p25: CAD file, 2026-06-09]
3d-files/3mf/Transporter/Transporter_Case.3mf
110.0 x 157.0 x 100.0 mm

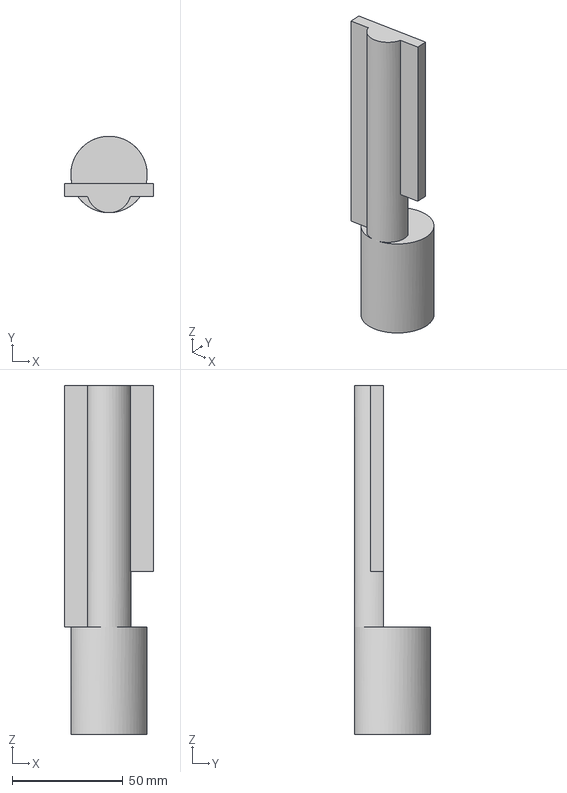
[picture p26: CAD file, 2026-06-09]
3d-files/3mf/Display/Bildschirmhalterung.3mf
40.0 x 34.5 x 157.5 mm

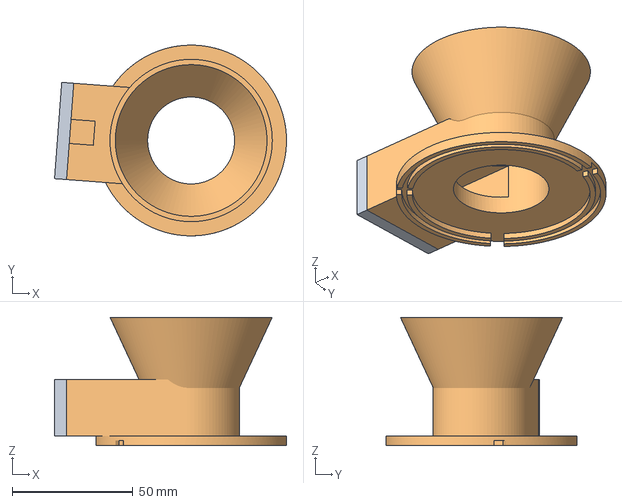
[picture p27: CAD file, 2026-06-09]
3d-files/3mf/Kamera/Deckel.3mf
96.1 x 79.0 x 53.2 mm
Lichtschranken_Kappe
Oberteil

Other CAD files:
3d-files/3mf/Tippything/Kurbelschleife.3mf
3d-files/3mf/Transporter/Tube_Curved_67.5°.3mf
3d-files/3mf/Kamera/Kameraholder.3mf
3d-files/3mf/Tippything/Tippything_Case.3mf
3d-files/3mf/Tippything/Box.3mf
3d-files/3mf/Tippything/Plexiglashalter.3mf
3d-files/3mf/Tippything/Track.3mf
3d-files/3mf/Transporter/Archimedes_Screw.3mf
3d-files/3mf/Transporter/Motor_Holder.3mf
3d-files/3mf/Transporter/Transporter_Adapter.3mf
3d-files/3mf/Transporter/Tube_Curved_90°.3mf
3d-files/3mf/Transporter/Tube_Straight.3mf
3d-files/f3d/Case.f3d
3d-files/f3d/Display/Bildschirmhalterung.f3d
3d-files/f3d/Display/MOSFET_Halterung.f3d
3d-files/f3d/Display/MotorController_Halterung.f3d
3d-files/f3d/Display/RaspberryPI_Halterung.f3d
3d-files/f3d/Kamera/Deckel.f3d
3d-files/f3d/Kamera/Kameraholder.f3d
3d-files/f3d/Kamera/MCP3008_Halter.f3d
3d-files/f3d/Kamera/Unterteil.f3d
3d-files/f3d/Kamera/main_chamber.f3d
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

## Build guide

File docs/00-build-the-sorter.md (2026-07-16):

# Step 0 — Build the Sorter

This guide walks you through building the marble sorter from scratch: the bill
of materials (with purchase links), the 3D-printed parts, the wiring and GPIO
pin map, and step-by-step mechanical assembly.

> **Machine:** Workbench
> **Time:** ~1–2 days (plus 3D-printing time)
> **Skill level:** Basic soldering, wiring, and 3D printing

Finished marble sorter

---

## How It Works

Marbles are lifted from a hopper by a motor-driven **Archimedes screw**, singled
out by a crank-driven feeder (the *Tippything*), and dropped one at a time
through a **camera chamber**. A ring of NeoPixel LEDs lights the marble while a
FLIR machine-vision camera captures it. The Coral Edge TPU classifies the
marble's color, and a **solenoid-actuated gate** diverts it left or right into
the correct bin. A touchscreen shows live detections and START/STOP controls.

```
Hopper → Archimedes screw (stepper) → Feeder → Camera chamber (LED + camera)
       → Classify (Coral TPU) → Solenoid gate → Sorted bins
```

---

## Bill of Materials (BOM)

> Quantities assume a single sorter.

### Compute & Vision

| # | Part | Qty | Notes | Link |
|---|---|-----|---|---|
| 1 | Raspberry Pi 4 (4 GB+) — or better | 1 | Main controller, runs the sorter software | [buy](https://www.raspberrypi.com/products/raspberry-pi-5/) |
| 2 | microSD card (32 GB+, A2/U3) — or better | 1 | OS + project files | [buy](https://www.sandisk.com/de-de/product-portfolio/memory-cards/microsd-cards) |
| 3 | Official Raspberry Pi 27 W USB-C PSU (Pi 5) | 1 | Stable 5 V/5 A supply for the Pi | [buy](https://www.berrybase.de/raspberry-pi-27w-usb-c-power-supply-netzteil-weiss) |
| 4 | Google Coral USB Accelerator | 1 | Edge TPU for real-time inference (~6 ms/frame) | [buy](https://www.berrybase.de/google-coral-usb-accelerator-fuer-raspberry-pi) |
| 5 | FLIR/Teledyne machine-vision camera (USB3, Bayer) | 1 | Captures the marbles (Spinnaker SDK) | [buy](https://www.teledynevisionsolutions.com/de-de/products/blackfly-s-usb3/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) |
| 6 | 4mm UC Series Fixed Focal Length Lens | 1 |  | [buy](https://www.edmundoptics.com/p/4mm-uc-series-fixed-focal-length-lens/2966/) |
| 7 | C/CS-mount lens for the camera | 1 | Match focal length to chamber distance | [buy](https://www.vision-dimension.com/de/objektive/objektiv-zubehoer/zwischenringe/zwischenring-5mm-c-cs-mount-adapter-hq/376) |
| 8 | USB 3.0 cable (locking, for the camera) | 1 | Camera ↔ Pi | [buy](https://www.amazon.com/AmazonBasics-USB-3-0-Cable-Male/dp/B00NH13G5A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) |
| 9 | Touchscreen display (DSI or HDMI, e.g. 7") | 1 | On-screen UI / START–STOP | [buy](https://www.berrybase.de/offizielles-raspberry-pi-7-display-mit-kapazitiven-touchscreen) |

### Motion & Actuation

| # | Part | Qty | Notes | Link |
|---|---|-----|---|---|
| 10 | NEMA 17 stepper motor | 1 | Drives the Archimedes screw transporter | [buy](https://www.omc-stepperonline.com/de/nema-17-bipolar-schrittmotor-42ncm-59-48oz-in-1-7a-42x42x37-5mm-4-adern-mit-1m-kabel-und-stecker-17he15-1704s) |
| 11 | Stepper driver (A4988 or DRV8825) | 1 | Mounted in `MotorController_Halterung` | [buy](https://www.reichelt.de/de/de/shop/produkt/entwicklerboards_-_schrittmotorsteuerung_a4988-282646?PROVID=2788) |
| 12 | 12 V solenoid (push/pull) | 1 | Actuates the sorting gate | [buy](https://www.amazon.de/TAU-0730B-0730S-Elektromagnet-Open-Frame-Solenoid-Elektromagnet-Druckhub/dp/B0DKBRJH9H) |
| 13 | Logic-level N-channel MOSFET module (e.g. IRLZ44N) | 1 | Switches the solenoid from a 3.3 V GPIO | [buy](https://www.reichelt.de/de/de/shop/produkt/entwicklerboards_-_mos_treiber_modul_3_3_5_v_0_24_v_irf52-282562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) |

### Lighting & Sensing

| # | Part | Qty | Notes | Link |
|---|---|-----|---|---|
| 14 | NeoPixel (WS2812B) ring(s), 24 LEDs total | 1–2 | Illuminates the camera chamber (firmware uses 24) | [buy](https://www.adafruit.com/product/1586) |
| 15 | MCP3008 8-channel ADC | 1 | Reads the analog light-beam sensor over SPI | [buy](https://www.reichelt.de/de/de/shop/produkt/10-bit_serieller_a_d-wandler_8-kanal_2_7v_spi_dip-16-280371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) |

### Power & Electronics

| # | Part | Qty | Notes | Link |
|---|---|-----|---|---|
| 16 | 9 V power supply (2 A) | 1 | Stepper + solenoid rail | [buy](https://www.conrad.de/de/p/hn-power-hnp06-090l6-steckernetzteil-festspannung-9-v-dc-840-ma-6-w-stabilisiert-1527541.html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) |

### Mechanical & Fasteners

| # | Part | Qty | Notes | Link |
|---|---|-----|---|---|
| 17 | Marbles to sort | a handful | Test material | [buy](https://amzn.eu/d/0aglnTU7) |
| 18 | Marbles to sort | a handful | Test material | [buy](https://amzn.eu/d/0dsa3RWX) |

### Filament

| # | Part | Qty | Notes | Link |
|---|---|-----|---|---|
| 19 | PLA or PETG filament | ~1 kg | For all printed parts (see below) | [buy](https://eu.store.bambulab.com/de/collections/pla) |

---

## 3D-Printed Parts

All source models live in [`3d-files/`](../3d-files): editable Fusion 360 files
in `f3d/` and ready-to-slice meshes in `3mf/`. Parts are grouped by
sub-assembly.

**Suggested print settings (starting point):**

| Setting | Value |
|---|---|
| Material | PLA (or PETG for higher temp/strength) |
| Layer height | 0.2 mm |
| Infill | 20 % (40 % for the motor/screw mounts) |
| Walls / perimeters | 3 |
| Supports | Only where noted below |

### Transporter (Archimedes screw lift) — [`3d-files/3mf/Transporter`](../3d-files/3mf/Transporter)

| File | Description | Supports |
|---|---|---|
| `Archimedes_Screw.3mf` | The screw that lifts marbles upward | Yes |
| `Motor_Holder.3mf` | Mount for the NEMA 17 stepper | No |
| `Transporter_Case.3mf` | Main body of the lift | Yes |
| `Transporter_Case_Wall.3mf` | Side wall / cover | No |
| `Transporter_Adapter.3mf` | Couples the transporter to the chamber | No |
| `Tube_Straight.3mf` | Straight marble guide tube | Yes |
| `Tube_Curved_67.5°.3mf` | 67.5° marble guide tube | Yes |
| `Tube_Curved_90°.3mf` | 90° marble guide tube | Yes |

Transporter assembly

### Feeder / "Tippything" (single-marble metering) — [`3d-files/3mf/Tippything`](../3d-files/3mf/Tippything)

| File | Description | Supports |
|---|---|---|
| `Tippything_Case.3mf` | Feeder housing | Yes |
| `Box.3mf` | Hopper / collection box | No |
| `Kurbelschleife.3mf` | Scotch-yoke (crank) that singles out marbles | No |
| `Kurbelschleifen_Funktionstester.3mf` | Test jig for the crank mechanism | No |
| `Track.3mf` | Marble track | No |
| `Rohr.3mf` | Tube | No |
| `Trichter.3mf` | Funnel | No |
| `Plexiglashalter.3mf` | Holder for the acrylic window | No |

Feeder / Tippything assembly

### Camera chamber — [`3d-files/3mf/Kamera`](../3d-files/3mf/Kamera)

| File | Description | Supports |
|---|---|---|
| `main_chamber.3mf` | Imaging chamber (holds the LED ring + window) | Yes |
| `Kameraholder.3mf` | Camera mount | No |
| `Deckel.3mf` | Chamber lid | No |
| `Unterteil.3mf` | Chamber base | No |
| `MCP3008_Halter.3mf` | Mount for the MCP3008 ADC board | No |

Camera chamber assembly

### Display & electronics mounts — [`3d-files/3mf/Display`](../3d-files/3mf/Display)

| File | Description | Supports |
|---|---|---|
| `Bildschirmhalterung.3mf` | Touchscreen mount | No |
| `RaspberryPI_Halterung.3mf` | Raspberry Pi mount | No |
| `MotorController_Halterung.3mf` | Stepper-driver mount | No |
| `MOSFET_Halterung.3mf` | MOSFET module mount | No |

Electronics & display mounts

### Outer case — [`3d-files/3mf/Case.3mf`](../3d-files/3mf)

| File | Description | Supports |
|---|---|---|
| `Case.3mf` | Main enclosure tying everything together | Yes |

Outer case

---

## Tools Required

- Soldering iron + solder (for the NeoPixel, MOSFET, and sensor wiring)
- Soldering iron tip / press for installing M3 heat-set inserts
- Screwdrivers and hex keys (M3)
- Wire cutters / strippers
- Multimeter (to verify rails before powering logic)
- 3D printer

---

## Wiring & GPIO Pin Map

All GPIO numbers are **BCM** (the same numbering the code uses). Pin assignments
come directly from the controller classes in [`actuator/`](../actuator) and
[`sensor/`](../sensor).

| Function | Component | Pi GPIO (BCM) | Source |
|---|---|---|---|
| Stepper ENABLE (active-low) | Stepper driver `EN` | **GPIO 17** | `actuator/elevator_motor.py` |
| Stepper DIR | Stepper driver `DIR` | **GPIO 27** | `actuator/elevator_motor.py` |
| Stepper STEP | Stepper driver `STEP` | **GPIO 22** | `actuator/elevator_motor.py` |
| Solenoid switch | MOSFET gate | **GPIO 16** | `actuator/switch_solenoid_motor.py` |
| NeoPixel data | LED ring `DIN` (via level shifter) | **GPIO 18** | `actuator/led_neopixel.py` |
| Light-beam ADC (SPI) | MCP3008 `CH0` | SPI0 (see below) | `sensor/light_beam.py` |

**MCP3008 ↔ Raspberry Pi (SPI0):**

| MCP3008 pin | Pi pin |
|---|---|
| `VDD` / `VREF` | 3.3 V |
| `AGND` / `DGND` | GND |
| `CLK` | SCLK (GPIO 11) |
| `DOUT` | MISO (GPIO 9) |
| `DIN` | MOSI (GPIO 10) |
| `CS/SHDN` | CE0 (GPIO 8) |

> Enable SPI on the Pi (`sudo raspi-config` → Interface Options → SPI) so the
> MCP3008 / light-beam sensor works.

### Power & safety notes

- The **stepper** and **solenoid** run from the **12 V** rail — keep this
  separate from the Pi's 5 V logic supply and join only the **grounds**.
- Put a **flyback diode** across the solenoid coil; switch it through the
  **MOSFET** on GPIO 16, never directly from a GPIO.
- Drive NeoPixel data through a **74AHCT125 level shifter** (3.3 V → 5 V) and add
  a **1000 µF capacitor** across the LED 5 V supply.
- The stepper `ENABLE` line is **active-low**; the firmware boots it HIGH
  (disabled) so the motor doesn't buzz or heat up at idle.

Wiring diagram

---

## Assembly

### 1. Print and prep parts

Print everything in the [3D-Printed Parts](#3d-printed-parts) section. Install
M3 heat-set inserts into the marked bosses. Cut the acrylic window to fit the
`Plexiglashalter`.

Printed parts laid out

### 2. Build the transporter

Fit the **Archimedes screw** into the `Transporter_Case`, mount the **NEMA 17
stepper** to the `Motor_Holder`, and couple it to the screw shaft. Close it with
the `Transporter_Case_Wall`.

Transporter build

### 3. Build the feeder (Tippything)

Assemble the `Tippything_Case`, install the `Kurbelschleife` (scotch-yoke)
mechanism, and attach the `Trichter` funnel and `Box` hopper. This meters
marbles one at a time onto the `Track`.

Feeder build

### 4. Build the camera chamber

Mount the **camera** to the `Kameraholder`, seat the **NeoPixel ring** inside
`main_chamber`, fit the acrylic window, and close it with `Deckel`/`Unterteil`.
Keep the inside matte black to avoid glare.

Camera chamber build

### 5. Mount electronics & display

Attach the **Raspberry Pi**, **stepper driver**, and **MOSFET module** to their
holders (`RaspberryPI_Halterung`, `MotorController_Halterung`,
`MOSFET_Halterung`). Mount the **touchscreen** to the `Bildschirmhalterung` and
the **MCP3008** to the `MCP3008_Halter`.

Electronics mounting

### 6. Wire everything

Wire according to the [pin map](#wiring--gpio-pin-map). Double-check the 12 V and
5 V rails with a multimeter **before** connecting the Pi.

Wiring in progress

### 7. Install the solenoid sorting gate

Mount the **solenoid** at the chamber outlet so its plunger swings the gate
between the two bins. Solenoid ON = one side, OFF = the other (default).

Solenoid gate

### 8. Final assembly

Combine all sub-assemblies into the `Case`, route and tidy the cables, and
attach the marble bins under the gate.

Final assembly

---

## First Power-On & Smoke Tests

Before running the full sorter, test each subsystem with the standalone scripts
(run from the project root). See [`actuator/README.md`](../actuator/README.md)
and [`sensor/README.md`](../sensor/README.md) for environment setup.

```bash
# Stepper / transporter
sudo .venv-3.10/bin/python actuator/motor_test.py

# Solenoid gate
sudo .venv-3.10/bin/python actuator/solenoid_test.py

# NeoPixel lighting
sudo .venv-3.10/bin/python actuator/neopixel_test.py

# Light-beam sensor
sudo .venv-3.10/bin/python sensor/light_beam.py

# Camera capture
sudo .venv-3.10/bin/python sensor/camera.py
```

If each part responds correctly, the hardware build is done.

---

**Next:** [Step 1 — Raspberry Pi Setup](01-raspberry-pi-setup.md)

[**Home**](../README.md)

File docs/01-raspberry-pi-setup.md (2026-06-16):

# Step 1 — Raspberry Pi Setup

This guide covers everything needed to get the Raspberry Pi ready to run the sorter.

> **Machine:** Raspberry Pi (Raspbian ARM64)

### 1.1 Clone the repository

```bash
git clone https://github.com/ITLab-CC/Sorter
cd Sorter
```

## 1.1 Install system dependencies

```bash
sudo apt update
sudo apt install -y \
    udev \
    ethtool \
    libusb-1.0-0 \
    iproute2 \
    iputils-ping \
    net-tools \
    build-essential \
    libssl-dev \
    zlib1g-dev \
    libbz2-dev \
    libreadline-dev \
    libsqlite3-dev \
    curl \
    git \
    libncursesw5-dev \
    xz-utils \
    tk-dev \
    libxml2-dev \
    libxmlsec1-dev \
    libffi-dev \
    liblzma-dev \
    libgl1 \
    libglib2.0-0 \
    ffmpeg \
    protobuf-compiler \
    libedgetpu1-max
```

## 1.2 Install pyenv and Python 3.10

```bash
curl https://pyenv.run | bash

LINE1='export PYENV_ROOT="$HOME/.pyenv"'
LINE2='command -v pyenv >/dev/null || export PATH="$PYENV_ROOT/bin:$PATH"'
LINE3='eval "$(pyenv init -)"'
grep -qF "$LINE1" ~/.bashrc || echo "$LINE1" >> ~/.bashrc
grep -qF "$LINE2" ~/.bashrc || echo "$LINE2" >> ~/.bashrc
grep -qF "$LINE3" ~/.bashrc || echo "$LINE3" >> ~/.bashrc
export PYENV_ROOT="$HOME/.pyenv"
command -v pyenv >/dev/null || export PATH="$PYENV_ROOT/bin:$PATH"
eval "$(pyenv init -)"

pyenv install 3.10.20
pyenv local 3.10.20
```

## 1.3 Create a virtual environment and install Python packages

```bash
python3.10 -m venv .venv-3.10
export SPINNAKER_GENTL64_CTI=/opt/spinnaker/lib/spinnaker-gentl/Spinnaker_GenTL.cti
.venv-3.10/bin/pip install --upgrade pip setuptools wheel
.venv-3.10/bin/pip install -r ./actuator/requirements-3.10.txt
.venv-3.10/bin/pip install -r ./sensor/requirements-3.10.txt
.venv-3.10/bin/pip install -r requirements-3.10.txt
```

## 1.4 Install Coral Edge TPU runtime (ARM64)

```bash
mkdir -p ~/coral-wheels
wget -O ~/coral-wheels/tflite_runtime-2.12.0-cp310-cp310-linux_aarch64.whl \
  "https://github.com/oberluz/pycoral/releases/download/2.12.0/tflite_runtime-2.12.0-cp310-cp310-linux_aarch64.whl"

wget -O ~/coral-wheels/pycoral-2.12.0-cp310-cp310-linux_aarch64.whl \
  "https://github.com/oberluz/pycoral/releases/download/2.12.0/pycoral-2.12.0-cp310-cp310-linux_aarch64.whl"

.venv-3.10/bin/pip install ~/coral-wheels/tflite_runtime-2.12.0-cp310-cp310-linux_aarch64.whl
.venv-3.10/bin/pip install ~/coral-wheels/pycoral-2.12.0-cp310-cp310-linux_aarch64.whl
```

## 1.5 Install the Spinnaker SDK (camera driver)

Download both the SDK and the Python bindings from the [Spinnaker SDK download page](https://www.teledynevisionsolutions.com/support/support-center/software-firmware-downloads/iis/spinnaker-sdk-download/spinnaker-sdk--download-files/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) and place them in the `sensor/` folder.

You need these two files (ARM64):

- `spinnaker-4.3.0.189-Ubuntu22.04-arm64-pkg.tar.gz` (Linux Ubuntu 22.04 --ARM64)
- `spinnaker_python-4.3.0.189-cp310-cp310-linux_aarch64.tar.gz` (Linux Ubuntu 22.04 -- ARM64 Python 3.10)

### Extract and install the SDK

```bash
mkdir -p sensor/spinnaker_sdk sensor/spinnaker_python
tar -xzvf sensor/spinnaker-4.3.0.189-Ubuntu22.04-arm64-pkg.tar.gz -C sensor/spinnaker_sdk
tar -xzvf sensor/spinnaker_python-4.3.0.189-cp310-cp310-linux_aarch64.tar.gz -C sensor/spinnaker_python

cd sensor/spinnaker_sdk/spinnaker-4.3.0.189-arm64/
./install_spinnaker_arm.sh
```

### Install the Python bindings

```bash
cd ../../spinnaker_python
../../.venv-3.10/bin/pip install spinnaker_python-4.3.0.189-cp310-cp310-linux_aarch64.whl
```

### Clean up

```bash
cd ../..
rm -rf sensor/spinnaker_python sensor/spinnaker_sdk
```

## 1.6 Set a safe GPIO state for the elevator stepper

At power-on the GPIO pins float until a program drives them. For the elevator
stepper driver this means the `ENABLE` pin can drift and energise the driver,
while the floating `STEP` pin picks up electrical noise — causing the motor to
hum or twitch/rotate on its own **even when no program is running**.

To hold the driver in a safe, defined state from boot, append the following
lines to the bottom of `/boot/firmware/config.txt` (older Raspberry Pi OS:
`/boot/config.txt`):

```bash
sudo tee -a /boot/firmware/config.txt > /dev/null <<'EOF'

# Elevator stepper driver: hold pins in a safe state from power-on so the
# motor does not twitch/rotate while no program is running.
# 17=ENABLE (active-low -> drive HIGH = disabled), 22=STEP, 27=DIR.
gpio=17=op,dh
gpio=22=op,dl
gpio=27=op,dl
EOF
```

Then reboot for the settings to take effect:

```bash
sudo reboot
```

> **Note:** `17` is the `ENABLE` pin. This assumes an active-low driver
> (A4988/DRV8825), so it is driven HIGH (`dh`) to keep the driver disabled.
> If your driver enables on HIGH instead, change `gpio=17=op,dh` to
> `gpio=17=op,dl`.

---

**Previous:** [Step 0 — Build the Sorter](00-build-the-sorter.md)
**Next:** [Step 2 — Training PC Setup](02-training-pc-setup.md)

[**Home**](../README.md)

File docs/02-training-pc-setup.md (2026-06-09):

# Step 2 — Training PC Setup

This guide sets up the PC you will use to train the AI model. You only need to do this once.

> **Machine:** PC with an NVIDIA GPU (Linux recommended)

## Requirements
Setup a PC which will be used for training the AI model. It should have an NVIDIA GPU and be running Linux. We tested this setup using ubuntu 24. It is also required to install the NVIDIA driver in a advance.

## 2.1 Clone the repository

```bash
git clone https://github.com/ITLab-CC/Sorter
cd Sorter
```

## 2.2 Install Docker

```bash
curl -sSL https://get.docker.com | sudo sh
```

## 2.3 Install the NVIDIA Container Toolkit

This lets Docker containers access the GPU.

```bash
sudo apt-get update && sudo apt-get install -y --no-install-recommends \
   ca-certificates \
   curl \
   gnupg2

curl -fsSL https://nvidia.github.io/libnvidia-container/gpgkey | sudo gpg --dearmor -o /usr/share/keyrings/nvidia-container-toolkit-keyring.gpg \
  && curl -s -L https://nvidia.github.io/libnvidia-container/stable/deb/nvidia-container-toolkit.list | \
    sed 's#deb https://#deb [signed-by=/usr/share/keyrings/nvidia-container-toolkit-keyring.gpg] https://#g' | \
    sudo tee /etc/apt/sources.list.d/nvidia-container-toolkit.list

sudo apt-get update

export NVIDIA_CONTAINER_TOOLKIT_VERSION=1.19.0-1
sudo apt-get install -y \
    nvidia-container-toolkit=${NVIDIA_CONTAINER_TOOLKIT_VERSION} \
    nvidia-container-toolkit-base=${NVIDIA_CONTAINER_TOOLKIT_VERSION} \
    libnvidia-container-tools=${NVIDIA_CONTAINER_TOOLKIT_VERSION} \
    libnvidia-container1=${NVIDIA_CONTAINER_TOOLKIT_VERSION}

sudo nvidia-ctk runtime configure --runtime=docker
sudo systemctl restart docker
```

## 2.4 Build the training Docker image

```bash
sudo docker build -f Dockerfile.train -t sorter-train:latest .
```

This image contains TensorFlow 2.11, the TF Object Detection API, the pretrained SSD MobileNet V2 checkpoint, and the Edge TPU compiler. You only need to build it once.

## 2.5 (Optional) Setup for test your AI model on a x86_64 PC (later)

If you also want to run inference tests on the training PC (e.g. with a Coral USB Accelerator plugged in):

```bash
sudo apt update
sudo apt install -y \
    udev \
    ethtool \
    libusb-1.0-0 \
    iproute2 \
    iputils-ping \
    net-tools \
    build-essential \
    libssl-dev \
    zlib1g-dev \
    libbz2-dev \
    libreadline-dev \
    libsqlite3-dev \
    curl \
    git \
    libncursesw5-dev \
    xz-utils \
    tk-dev \
    libxml2-dev \
    libxmlsec1-dev \
    libffi-dev \
    liblzma-dev \
    libgl1 \
    libglib2.0-0 \
    ffmpeg \
    protobuf-compiler \
    libedgetpu1-max

curl https://pyenv.run | bash

LINE1='export PYENV_ROOT="$HOME/.pyenv"'
LINE2='command -v pyenv >/dev/null || export PATH="$PYENV_ROOT/bin:$PATH"'
LINE3='eval "$(pyenv init -)"'
grep -qF "$LINE1" ~/.bashrc || echo "$LINE1" >> ~/.bashrc
grep -qF "$LINE2" ~/.bashrc || echo "$LINE2" >> ~/.bashrc
grep -qF "$LINE3" ~/.bashrc || echo "$LINE3" >> ~/.bashrc
export PYENV_ROOT="$HOME/.pyenv"
command -v pyenv >/dev/null || export PATH="$PYENV_ROOT/bin:$PATH"
eval "$(pyenv init -)"

pyenv install 3.10.20
pyenv local 3.10.20

python3.10 -m venv .venv-3.10
.venv-3.10/bin/pip install --upgrade pip setuptools wheel
.venv-3.10/bin/pip install -r requirements-3.10.txt

mkdir -p ~/coral-wheels
wget -O ~/coral-wheels/tflite_runtime-2.5.0.post1-cp310-cp310-linux_x86_64.whl \
  "https://github.com/cappittall/pycoral_whl_4_python3.10/raw/main/tools/tflite_runtime-2.5.0.post1-cp310-cp310-linux_x86_64.whl"
wget -O ~/coral-wheels/pycoral-2.0.0-cp310-cp310-linux_x86_64.whl \
  "https://github.com/cappittall/pycoral_whl_4_python3.10/raw/main/tools/pycoral-2.0.0-cp310-cp310-linux_x86_64.whl"
.venv-3.10/bin/pip install ~/coral-wheels/tflite_runtime-2.5.0.post1-cp310-cp310-linux_x86_64.whl
.venv-3.10/bin/pip install ~/coral-wheels/pycoral-2.0.0-cp310-cp310-linux_x86_64.whl
```

---

**Previous:** [Step 1 — Raspberry Pi Setup](01-raspberry-pi-setup.md)
**Next:** [Step 3 — Create a Dataset](03-create-dataset.md)

[**Home**](../README.md)

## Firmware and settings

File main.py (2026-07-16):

"""Marble Sorter – Main control loop.

Runs the full sorting pipeline, controlled by START/STOP buttons in the
on-screen display:
1. Verify the Coral Edge TPU model file exists.
2. Initialise hardware and show the fullscreen display.
3. Wait until the user presses START (statistics are cleared on each start).
4. While running, stream camera frames and detect marble presence via OpenCV.
5. If detected, classify with the Coral Edge TPU model.
6. Trigger the solenoid to sort left/right based on color.
7. Keep running until STOP is pressed, then return to step 3.
8. Exit cleanly only when the window is closed or on Ctrl+C.

Usage:
    sudo .venv-3.10/bin/python main.py
"""

import os
import re
import sys
import time
import threading

import cv2
import numpy as np
from PIL import Image
from pycoral.adapters import common, detect
from pycoral.utils.edgetpu import make_interpreter

from actuator.elevator_motor import ElevatorMotorController
from actuator.led_neopixel import NeoPixelController
from actuator.switch_solenoid_motor import SolenoidController
from sensor.camera import Camera
from display import MarbleDisplay

# ---------------------------------------------------------------------------
# Paths
# ---------------------------------------------------------------------------
MODEL_PATH = "my-models/marbel_coral.tflite"
LABELS_PATH = "my-models/labels.txt"
LABEL_MAP_PATH = "label_map.pbtxt"

# ---------------------------------------------------------------------------
# Sorting parameters
# ---------------------------------------------------------------------------
SORT_DURATION = 30          # seconds
DETECTION_THRESHOLD = 0.4   # minimum confidence for a detection
COOLDOWN_SECONDS = 0.5      # pause after sorting a marble to avoid re-detecting

# Only classify/sort a marble when its detected centre lies within this
# fraction of the frame (width and height) around the image centre. e.g. 0.50
# means the marble's centre must be inside the central 50% band. Increase to
# accept marbles further from the middle; decrease to require tighter centring.
# If some marbels are not detected set this to 1.
CENTER_TOLERANCE = 1.0

# ---------------------------------------------------------------------------
# OpenCV marble-presence detection (mirrored from label_dataset.py)
# ---------------------------------------------------------------------------
CROP_SIZE_X = 300
CROP_SIZE_Y = 540
MIN_AREA = 2000
MAX_AREA = 100000
THRESH_VAL = 100

# ---------------------------------------------------------------------------
# Elevator motor
# ---------------------------------------------------------------------------
ELEVATOR_STEPS = 400
ELEVATOR_PAUSE = 0.002


# ═══════════════════════════════════════════════════════════════════════════
# Helpers
# ═══════════════════════════════════════════════════════════════════════════

def load_labels():
    """Load class labels from labels.txt or label_map.pbtxt.

    Returns a ``{id: name}`` dict (0-indexed as expected by pycoral).
    """
    labels = {}

    # Prefer my-models/labels.txt (format: "id name")
    if os.path.exists(LABELS_PATH):
        with open(LABELS_PATH, "r") as fh:
            for line in fh:
                pair = line.strip().split(maxsplit=1)
                if len(pair) == 2:
                    labels[int(pair[0])] = pair[1]
        return labels

    # Fall back to label_map.pbtxt (1-indexed, so subtract 1)
    if os.path.exists(LABEL_MAP_PATH):
        text = open(LABEL_MAP_PATH).read()
        for block in re.finditer(r"item\s*\{(.*?)\}", text, re.DOTALL):
            body = block.group(1)
            id_match = re.search(r"id:\s*(\d+)", body)
            name_match = re.search(r"name:\s*'([^']+)'", body)
            if id_match and name_match:
                labels[int(id_match.group(1)) - 1] = name_match.group(1)
        return labels

    print("Warning: No label file found. Using numeric class IDs.")
    return labels


def detect_marble_present(frame_bayer, crop_size=300, min_area=2000, max_area=100000,
                          thresh_val=100, require_centered=True,
                          center_tolerance=CENTER_TOLERANCE):
    """
    Detects if a marble is present in the center of the given image.

    Args:
        frame_bayer (np.ndarray): The input bayer image.
        crop_size (int): Size of the center square crop.
        min_area (int): Minimum contour area to be considered a marble.
        max_area (int): Maximum contour area to be considered a marble.
        thresh_val (int): Threshold value for binarization.
        require_centered (bool): If True, only count a marble when its centre
            lies within ``center_tolerance`` of the crop centre. Set to False
            to accept a marble anywhere inside the crop.
        center_tolerance (float): Fraction (0-1) of the crop width/height that
            forms the central band the marble centre must fall within.

    Returns:
        bool: True if a marble is detected, False otherwise.
    """
    # 1. Check Image
    if frame_bayer is None:
        print("Warning: Could not load image")
        return False

    height, width = frame_bayer.shape[:2]

    # 2. Fast Cropping
    start_x = max(0, width // 2 - crop_size // 2)
    start_y = max(0, height // 2 - crop_size // 2)

    # Slice the numpy array
    center_crop = frame_bayer[start_y:start_y+crop_size, start_x:start_x+crop_size]

    # 3. Optimized Processing (Grayscale -> Blur -> Threshold -> Invert)
    frame_gray = cv2.cvtColor(center_crop, cv2.COLOR_BAYER_RG2GRAY)
    blurred = cv2.GaussianBlur(frame_gray, (5, 5), 0)

    _, thresh = cv2.threshold(blurred, thresh_val, 255, cv2.THRESH_BINARY)
    inv_thresh = cv2.bitwise_not(thresh)

    # 4. Contour Detection
    contours, _ = cv2.findContours(inv_thresh, cv2.RETR_EXTERNAL, cv2.CHAIN_APPROX_SIMPLE)

    # 5. Validation
    # A contour matching the area criteria means a marble is present. When
    # require_centered is set, its centroid must also sit within the central
    # band of the crop, so marbles drifting in/out of frame are ignored.
    crop_h, crop_w = inv_thresh.shape[:2]
    cx_lo = crop_w * (0.5 - center_tolerance / 2)
    cx_hi = crop_w * (0.5 + center_tolerance / 2)
    cy_lo = crop_h * (0.5 - center_tolerance / 2)
    cy_hi = crop_h * (0.5 + center_tolerance / 2)

    for c in contours:
        area = cv2.contourArea(c)
        if not (min_area <= area <= max_area):
            continue
        if not require_centered:
            return True
        moments = cv2.moments(c)
        if moments["m00"] == 0:
            continue
        cx = moments["m10"] / moments["m00"]
        cy = moments["m01"] / moments["m00"]
        if cx_lo <= cx <= cx_hi and cy_lo <= cy <= cy_hi:
            return True

    return False


def run_elevator(motor, running_event, quit_event):
    """Rotate the elevator motor while *running_event* is set.

    Runs until *quit_event* is set (full program shutdown). The driver is only
    energised while the sorter is actually running; when stopped it is disabled
    so the motor has no holding current (no constant tension/heat) and cannot
    twitch from electrical noise.
    """
    enabled = False
    try:
        while not quit_event.is_set():
            if running_event.is_set():
                if not enabled:
                    motor.enable()
                    enabled = True
                motor.rotate(steps=ELEVATOR_STEPS, pause_seconds=ELEVATOR_PAUSE)
            else:
                if enabled:
                    motor.disable()
                    enabled = False
                time.sleep(0.05)
    finally:
        motor.disable()


# ═══════════════════════════════════════════════════════════════════════════
# Main
# ═══════════════════════════════════════════════════════════════════════════

def main():
    # ------------------------------------------------------------------
    # 1. Check that the Coral model is present
    # ------------------------------------------------------------------
    if not os.path.isfile(MODEL_PATH):
        sys.exit(
            f"Model not found: {MODEL_PATH}\n"
            "Copy marbel_coral.tflite into my-models/ first "
            "(see docs/05-run-sorter.md)."
        )
    print(f"[OK] Model found: {MODEL_PATH}")

    # ------------------------------------------------------------------
    # 2. Load labels & Coral interpreter
    # ------------------------------------------------------------------
    labels = load_labels()
    print(f"[OK] Labels: {labels}")

    try:
        interpreter = make_interpreter(MODEL_PATH)
        interpreter.allocate_tensors()
    except Exception as exc:
        sys.exit(
            f"Failed to load Coral model: {exc}\n"
            "Make sure the Coral USB Accelerator is connected and drivers "
            "are installed."
        )
    input_size = common.input_size(interpreter)
    print(f"[OK] Coral interpreter ready - input size {input_size}")

    # ------------------------------------------------------------------
    # 3. Initialise hardware
    # ------------------------------------------------------------------
    elevator = ElevatorMotorController()
    leds = NeoPixelController()
    solenoid = SolenoidController()
    cam = Camera()

    # Sleep mode: after a period of inactivity the display blanks itself and
    # the NeoPixels switch off. Touching the screen wakes everything back up.
    def _on_sleep() -> None:
        leds.turn_off()

    def _on_wake() -> None:
        # Restore the LEDs to the state matching the current mode.
        if display.running.is_set():
            leds.set_color((255, 255, 255), 0.5)
        else:
            leds.set_color((0, 255, 0), 0.05)

    display = MarbleDisplay(on_sleep=_on_sleep, on_wake=_on_wake)

    if cam.camera is None:
        sys.exit("No camera detected. Exiting.")
    cam.print_camera_info()
    # Disable auto-exposure and force a short shutter so fast-moving marbles
    # are captured sharply instead of motion-blurred.
    cam.unlock_max_framerate()

    # ------------------------------------------------------------------
    # 4. Start elevator (background thread).
    #    It only spins while the user has pressed START (display.running).
    # ------------------------------------------------------------------
    elevator_thread = threading.Thread(
        target=run_elevator,
        args=(elevator, display.running, display.quit),
        daemon=True,
    )
    elevator_thread.start()
    print("[OK] Elevator thread ready (idle until START).")

    # ------------------------------------------------------------------
    # 6. Main control loop
    #    Wait for the user to press START, sort until STOP is pressed, then
    #    return to waiting. The program only exits when the window is closed
    #    (display.quit) or on Ctrl+C.
    # ------------------------------------------------------------------
    print("\n--- Ready. Press START in the window to begin sorting. ---\n")

    # Ready state: light the NeoPixel rings a soft green until the user starts.
    leds.set_color((0, 255, 0), 0.05)

    try:
        while not display.quit.is_set():
            # Wait (idle) until the user presses START.
            while not display.running.is_set() and not display.quit.is_set():
                time.sleep(0.05)
            if display.quit.is_set():
                break

            # New session: clear all statistics and light up.
            frame_count = 0
            sorted_count = 0
            sort_stats = {"red": 0, "green": 0, "orange": 0, "black": 0}
            leds.set_color((255, 255, 255), 0.5)
            print("\n--- Sorting started ---\n")

            for raw_frame in cam.stream_while_running(
                lambda: display.running.is_set() and not display.quit.is_set()
            ):
                frame_count += 1

                # Convert raw Bayer to BGR
                frame_bgr = cv2.cvtColor(raw_frame, cv2.COLOR_BAYER_BG2BGR) #cv2.COLOR_BAYER_BG2BGR

                # Fast check: is there a marble in the frame?
                is_marbel = detect_marble_present(raw_frame)
                if is_marbel is False:
                    continue

                print("OPENCV erkannt")
                start_time = time.perf_counter()

                # Classify the detected marble with the Coral TPU
                pil_img = Image.fromarray(cv2.cvtColor(raw_frame, cv2.COLOR_BAYER_RG2BGR))
                pil_img = pil_img.resize(input_size, Image.LANCZOS)
                common.set_input(interpreter, pil_img)
                interpreter.invoke()
                objs = detect.get_objects(interpreter, DETECTION_THRESHOLD)

                inference_time = time.perf_counter() - start_time

                if not objs:
                    continue

                best = max(objs, key=lambda o: o.score)
                label = labels.get(best.id, f"unknown_{best.id}")
                confidence = best.score * 100
                sorted_count += 1

                # The model bbox is in the input-tensor space (input_size),
                # so scale it back to the full-resolution frame and convert
                # from (xmin, ymin, xmax, ymax) to (x, y, w, h).
                fh, fw = frame_bgr.shape[:2]
                scale_x = fw / input_size[0]
                scale_y = fh / input_size[1]
                bb = best.bbox
                disp_bbox = (
                    int(bb.xmin * scale_x),
                    int(bb.ymin * scale_y),
                    int((bb.xmax - bb.xmin) * scale_x),
                    int((bb.ymax - bb.ymin) * scale_y),
                )

                # Solenoid ON  → deflect to GREEN side (left)
                # Solenoid OFF → marble falls to RED side (right, default)
                display.update_detection(frame_bgr, label, confidence, disp_bbox)

                if label == "green":
                    solenoid.turn_on()
                    sort_stats["green"] += 1
                    print(f"  Frame {frame_count}: {label} ({confidence:.1f}%) -> LEFT ({inference_time*1000:.2f}ms)")
                elif label == "red":
                    solenoid.turn_off()
                    sort_stats["red"] += 1
                    print(f"  Frame {frame_count}: {label} ({confidence:.1f}%) -> RIGHT ({inference_time*1000:.2f}ms)")
                elif label == "orange":
                    solenoid.turn_on()
                    sort_stats["orange"] += 1
                    print(f"  Frame {frame_count}: {label} ({confidence:.1f}%) -> LEFT ({inference_time*1000:.2f}ms)")
                elif label == "black":
                    solenoid.turn_off()
                    sort_stats["black"] += 1
                    print(f"  Frame {frame_count}: {label} ({confidence:.1f}%) -> RIGHT ({inference_time*1000:.2f}ms)")

                # Cooldown so we don't re-classify the same marble
                time.sleep(COOLDOWN_SECONDS)

                cam.flush_image_queue()

            # Session stopped (STOP pressed or window closed).
            solenoid.turn_off()
            # Back to the ready state: green again (unless we're shutting down).
            if not display.quit.is_set():
                leds.set_color((0, 255, 0), 0.05)
            else:
                leds.turn_off()

            print(f"\n{'=' * 30}")
            print("      SORTING RESULTS")
            print(f"{'=' * 30}")
            print(f"  Frames processed : {frame_count}")
            print(f"  Marbles sorted   : {sorted_count}")
            print(f"  Red   (right)    : {sort_stats['red']}")
            print(f"  Green (left)     : {sort_stats['green']}")
            print(f"  Orange (left)    : {sort_stats['orange']}")
            print(f"  Black (right)    : {sort_stats['black']}")
            print(f"{'=' * 30}")
            if not display.quit.is_set():
                print("\n--- Sorting stopped. Press START to run again. ---\n")

    except KeyboardInterrupt:
        print("\nSorting interrupted by user.")

    finally:
        # --------------------------------------------------------------
        # 7. Shutdown
        # --------------------------------------------------------------
        print("\nShutting down...")

        display.running.clear()
        display.quit.set()
        display.close()
        elevator_thread.join(timeout=5)
        elevator.cleanup()
        print("[OK] Elevator stopped.")

        solenoid.turn_off()
        print("[OK] Solenoid off.")

        leds.turn_off()
        print("[OK] LEDs off.")

        cam.release_camera()
        print("[OK] Camera released.")


if __name__ == "__main__":
    main()

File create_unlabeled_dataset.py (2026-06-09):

import threading
import time
from typing import List
import os
import glob
import re

import numpy as np
import cv2

from actuator.elevator_motor import ElevatorMotorController
from actuator.led_neopixel import NeoPixelController
from sensor.camera import Camera

LABEL_MAP_PATH = "label_map.pbtxt"


def parse_label_map(path):
    """Parse a label_map.pbtxt file and return a ``{name: id}`` dict."""
    if not os.path.exists(path):
        return {}
    text = open(path).read()
    label_map = {}
    for block in re.finditer(r'item\s*\{(.*?)\}', text, re.DOTALL):
        body = block.group(1)
        id_match = re.search(r'id:\s*(\d+)', body)
        name_match = re.search(r"name:\s*'([^']+)'", body)
        if id_match and name_match:
            label_map[name_match.group(1)] = int(id_match.group(1))
    return label_map


def add_label_to_map(path, label_name):
    """Add a label to label_map.pbtxt if it doesn't exist yet. Returns the assigned ID."""
    label_map = parse_label_map(path)
    if label_name in label_map:
        print(f"Label '{label_name}' already exists in {path} with id {label_map[label_name]}")
        return label_map[label_name]

    next_id = max(label_map.values(), default=0) + 1
    with open(path, "a") as f:
        f.write(f"\nitem {{\n  id: {next_id}\n  name: '{label_name}'\n}}\n")
    print(f"Added label '{label_name}' with id {next_id} to {path}")
    return next_id


def run_motor_until_stopped(
    motor: ElevatorMotorController,
    stop_event: threading.Event,
    pause_seconds: float = 0.002,
    steps_per_batch: int = 200,
) -> None:
    """Continuously rotate the elevator motor until stop_event is set."""
    try:
        motor.enable()
        while not stop_event.is_set():
            motor.rotate(steps=steps_per_batch, pause_seconds=pause_seconds)
    except Exception as exc:
        print(f"Motor thread error: {exc}")

def contains_marble(frame_bayer, crop_size=300, min_area=2000, max_area=100000, thresh_val=100):
    """
    Detects if a marble is present in the center of the given image.
    
    Args:
        frame_bayer (np.ndarray): The input bayer image.
        crop_size (int): Size of the center square crop.
        min_area (int): Minimum contour area to be considered a marble.
        max_area (int): Maximum contour area to be considered a marble.
        thresh_val (int): Threshold value for binarization.
        
    Returns:
        bool: True if a marble is detected, False otherwise.
    """
    # 1. Check Image
    if frame_bayer is None:
        print("Warning: Could not load image")
        return False

    height, width = frame_bayer.shape[:2]

    # 2. Fast Cropping
    start_x = max(0, width // 2 - crop_size // 2)
    start_y = max(0, height // 2 - crop_size // 2)
    
    # Slice the numpy array
    center_crop = frame_bayer[start_y:start_y+crop_size, start_x:start_x+crop_size]

    # 3. Optimized Processing (Grayscale -> Blur -> Threshold -> Invert)
    frame_gray = cv2.cvtColor(center_crop, cv2.COLOR_BAYER_RG2GRAY)
    blurred = cv2.GaussianBlur(frame_gray, (5, 5), 0)
    
    _, thresh = cv2.threshold(blurred, thresh_val, 255, cv2.THRESH_BINARY)
    inv_thresh = cv2.bitwise_not(thresh)

    # 4. Contour Detection
    contours, _ = cv2.findContours(inv_thresh, cv2.RETR_EXTERNAL, cv2.CHAIN_APPROX_SIMPLE)

    # 5. Validation
    # If any contour matches the area criteria, a marble is present
    for c in contours:
        area = cv2.contourArea(c)
        if min_area <= area <= max_area:
            return True

    return False


def main() -> None:

    # Ask the label name
    label_name = input("Enter the label name: ").strip().lower()
    if not label_name:
        print("Label name cannot be empty.")
        return

    # Add label to label_map.pbtxt (skips if already present)
    add_label_to_map(LABEL_MAP_PATH, label_name)

    # Ask how long it should run
    capture_seconds = int(input("Enter the capture time in seconds: "))

    # Create label folder
    out_dir = os.path.join("dataset", label_name)
    os.makedirs(out_dir, exist_ok=True)

    led_color = (255, 255, 255)

    leds = NeoPixelController()
    motor = ElevatorMotorController()
    camera = Camera()

    stop_motor_event = threading.Event()
    motor_thread = threading.Thread(
        target=run_motor_until_stopped,
        args=(motor, stop_motor_event),
        daemon=True,
    )

    frames_to_save: List[np.ndarray] = []
    frames_processed = 0

    try:
        print("Turning LEDs on...")
        leds.set_color(led_color)

        print("Starting elevator motor...")
        motor_thread.start()

        print(f"Capturing and processing images live for {capture_seconds} seconds...")
        camera.print_camera_info()
        camera.unlock_max_framerate()
        
        # Initialize background subtractor BEFORE the loop
        backSub = cv2.createBackgroundSubtractorMOG2(history=20, varThreshold=50, detectShadows=False)
        kernel = cv2.getStructuringElement(cv2.MORPH_ELLIPSE, (5, 5))

        # Consume the camera stream live
        for frame_ref in camera.stream_for_duration(capture_seconds):
            frames_processed += 1
            
            # analyse image with contains_marble
            if contains_marble(frame_ref):
                frames_to_save.append(frame_ref.copy())
                print(f"Marble detected in frame {frames_processed}. Total kept frames: {len(frames_to_save)}")


    except KeyboardInterrupt:
        print("Interrupted by user.")

    finally:
        print("Stopping elevator motor...")
        stop_motor_event.set()
        motor_thread.join(timeout=2.0)
        motor.cleanup()

        print("Turning LEDs off...")
        time.sleep(1)
        leds.turn_off()

        print("Releasing camera...")
        camera.release_camera()

        # --- Save only centered frames to disk ---
        if frames_to_save:
            # 1. Find all existing frame images in the output folder
            search_pattern = os.path.join(out_dir, "frame_*.png")
            existing_files = glob.glob(search_pattern)

            # 2. Extract the numbers and find the highest one
            highest_idx = -1
            for filepath in existing_files:
                filename = os.path.basename(filepath) # e.g., 'frame_0042.png'
                try:
                    # Split by '_' and '.' to extract '0042', then convert to integer
                    num = int(filename.split('_')[1].split('.')[0])
                    if num > highest_idx:
                        highest_idx = num
                except (IndexError, ValueError):
                    # Ignore any files that happen to match the glob but don't parse cleanly
                    pass 

            # 3. Set the new starting index (if no files exist, highest_idx is -1, so start_idx becomes 0)
            start_idx = highest_idx + 1

            print(f"Writing kept frames to disk, continuing from frame_{start_idx:04d}...")
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

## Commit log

2024-10-14 ✨ feat: Add gitignore
2024-10-16 🐞 fix: int8 error
2024-10-16 🦄 refactor: move old files
    Moved old files in the old folder
2024-10-31 ✨ feat: Socket Connection
    Added Socket connection, diagnose scripts
2024-11-07 ✨ feat: Serial Connection - Arduino Serial Connection - Socket Server - Solonoid controll via TPU
    [pyvenv.cfg]
2024-11-08 ✨ 🎉 Camera
2024-11-08 🚧 Image TCP Server
2024-11-20 ✨ connect both scripts
2024-11-20 ✨ Add Makefile and retry connecting
2024-11-26 👷 update makefill
2024-11-26 🐛 optimize bind socket
2024-11-27 :bug: Fix make build on new device
2024-12-04 💚 🐛 install spinnaker_sdk
2024-12-04 🐛 🙈 Fix kill
2026-04-16 🙈 fix
2026-04-16 🚧 py actuator
2026-04-17 ♻️ Add actuator and sensor modules
2026-04-17 🚨 mypy
2026-04-17 📝 python versions
2026-04-20 ♻️ Update installation instructions, refine camera resource management, and enhance Dockerfile setup
2026-04-21 📝 Add camera docker README
2026-04-21 🙈 logs
2026-04-21 ✨ Enhance camera functionality with frame capture and unlock framerate; update requirements for psutil
2026-04-21 ♻️ Refactor Dockerfile to support arm
2026-04-21 ✨ Save first and last frames for visual confirmation after capture
2026-04-21 🙈 For test img
2026-04-21 📝 Add Python version files and update README for installation and usage instructions
2026-04-21 ♻️ Refactor to object oriented
2026-04-21 📝 Update installation instructions and requirements for Python 3.10
2026-04-21 📝 Update README for installation instructions and remove outdated content
2026-04-21 📝 Comment out code for saving all frames
2026-04-21 🐛 Fix docker img out dir
    [camera.py]
2026-04-21 🚧 Marbel detection + create dataset
2026-04-21 ✨ Update frame saving logic to continue from the highest existing index and increase capture duration
2026-04-21 ✨ Add color detection
2026-04-21 ✨ Refactor marble detection script: enhance color classification and streamline image processing
2026-04-22 🐛 Fix color conversion in frame saving logic from Bayer format
    [main.py]
2026-04-22 ✨ Create dataset
2026-04-22 ✨ Update Label Studio setup in README
2026-04-24 🚧 train ai
2026-04-27 📝 train ai inside docker
2026-04-27 🐛 training error
2026-04-27 ✨ run air
2026-04-27 ⚡️ speed up ai
2026-04-27 ⬆️ Use pythpon3.10
2026-04-30 📝 add more installation steps
2026-05-05 🔒️ set dataset directory for HTTP server
2026-05-05 📝 Rewrite detailed setup guides for building, configuring, and running the AI sorter
2026-05-07 🐛 change dataset json structure for labelstudio
2026-05-07 📝 test & improve docs
2026-05-07 📝 Update images path
2026-05-11 🔧 Use label_map.pbtxt as single source of truth for all class labels
2026-05-12 🚧 working sorter
2026-05-12 ✨ Add new 3D model files for all components as 3MF and F3D
    [Archimedes_Screw.3mf, Archimedes_Screw.f3d, Bildschirmhalterung.3mf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]
2026-06-09 ⚡️ Optimize marble detection and camera streaming for faster inference
2026-06-09 📝 Add platform details to Spinnaker downloads and reorder Label Studio screenshot
2026-06-09 ✨ Add fullscreen tkinter display with live marble detection and running counters
2026-06-09 🐛 fix color conversion
    [main.py]
2026-06-16 🐛 Fix display
2026-06-16 ✨ Add START/STOP button control to marble sorter with session-based statistics
2026-06-16 🐛 Fix fullscreen display on Raspberry Pi by forcing geometry and window attributes
    [display.py]
2026-06-16 🐛 Fix button visibility by forcing widget redraws and keeping control button on top
    [display.py]
2026-06-16 📝 Add autostart instructions for running marble sorter on boot using labwc and screen
2026-06-16 🚀 Enable max framerate by disabling auto-exposure for sharp marble capture
2026-06-16 ✨ Add runtime brightness control to NeoPixel LEDs with property setter and status lighting states
2026-06-16 🐛 Fix button overlap by packing banner last and reserving button space first
    [display.py]
2026-06-16 🎨 Change default LED color from yellow-orange to white
2026-06-16 🐛 Fix stepper motor twitching by setting safe GPIO states on boot and disabling driver when idle
    [elevator_motor.py, main.py]
2026-06-16 🐛 Fix autostart layout by recomputing dimensions when compositor updates screen size
    [display.py]
2026-06-16 ✨ Add sleep mode with screen blanking and LED control after 30s of inactivity
2026-06-16 🐛 Fix marble sorting logic to turn off solenoid for unclassified marbles
    [main.py]
2026-06-17 🎨 Update statistics display colors and layout for marble sorting
2026-06-18 🎨 Scale detection bounding box to full frame resolution for display overlay
2026-06-18 🐛 Force display on at startup to prevent dark screen on Pi systems with DPMS/screensaver active
    [display.py]
2026-06-18 ✨ Add center tolerance parameter to marble detection to ignore marbles at frame edges
    [main.py]
2026-06-18 ✨ Add pretrained model to allow running sorter without training steps
2026-06-18 🚧 Add complete build guide with BOM, wiring diagram, and assembly instructions
2026-06-26 🎨 Added statistics display colors
2026-07-16 🔧 Increase center tolerance to 1.0 to detect all marbles regardless of position in frame
    [main.py]
2026-07-16 📝 Update build guide with actual product links and corrected image file extensions
2026-09-23 🚧 add digital twin
